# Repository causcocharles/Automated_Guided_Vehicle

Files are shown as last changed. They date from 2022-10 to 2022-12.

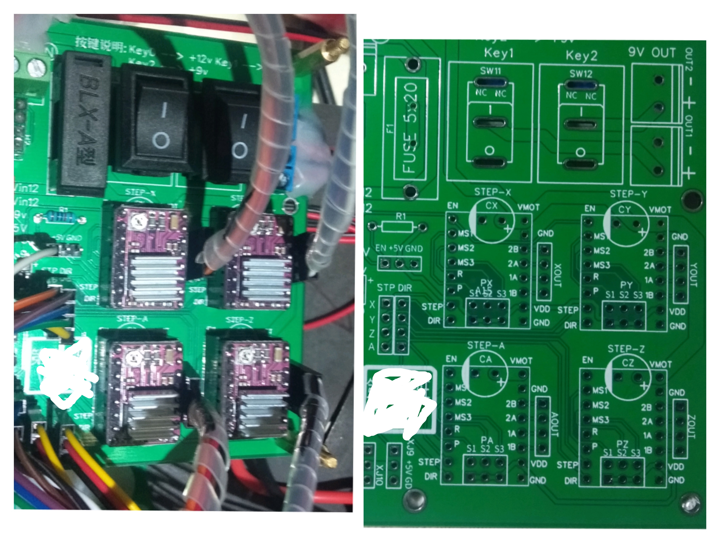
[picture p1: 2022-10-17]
视觉+驱动+机械臂Arduino_21年工训大赛全国季军开源代码/（参考方案）Project_V1.0_四路步进电机驱动板/实物参考图--拓展了其他内容.jpg

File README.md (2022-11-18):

# Automated_Guided_Vehicle
Project codes and reference material of automated guided vehicle for Engineering Innovation Competition. 工程创新大赛智能物流小车项目资料和代码。

目录
- 1. 底盘运动控制文件
- 2. 机械臂控制文件
- 3. 视觉文件
- 4. 机械设计_图纸_建模
  - 底盘
  - 机械臂
  - 载物台
  - 其他 
- 5. 大赛细则及规范
- 6. 其他
- 7. 方案文档
- 8. Sunnybot旧版官方库，内含电机驱动、机械臂控制和OpenMV使用的示例程序
- 9. UTFT库，官方提供的OLED显示转换库
- 10. PS2遥控器官方库
- 11. espbot库——Sunnybot新版库（支持esp32S3）
- 12. Sunnybot-ARM机械臂库（新版）
- 工程实践创新大赛备赛参考资料：https://zhuanlan.zhihu.com/p/365851952
- 视觉相关OpenMV官方指南：https://book.openmv.cc/
- PID算法优化：http://brettbeauregard.com/blog/2011/04/improving-the-beginners-pid-introduction/
- Arduino理论速成指南：https://blog.csdn.net/xq151750111/category_10847153.html
- 配件购买及备赛指南：https://zhuanlan.zhihu.com/p/433498924
- 文本生成二维码网站：https://cli.im/text
- 8/9/10 三个库文件请自行安装，不会的找阿欢

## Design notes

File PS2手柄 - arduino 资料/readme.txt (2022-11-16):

PS手柄 - arduino 通信

1、准备好PS2手柄及arduino UNO R3控制板

2、安装好arduino IDE 后，将PS2X_lib.zip解压到C:\Users\Administrator\Documents\Arduino\libraries文件夹中！

3、按照连接图连接好接收器与控制板（关键一步，基本上都是在这里出错导致无法通信）

4、烧写例程

5、手柄安装上电池后，打开开关 - 电源红灯亮，如果绿灯未亮，点击MODE按钮！打开后，手柄与接收器会自动配对，成功配对后手柄红绿灯常亮，接收器灯常亮。

6、打开串口监视器，点击各个按钮，确定数据通信正常！

如果不正常，检查上面 2、3、4、5步骤！！

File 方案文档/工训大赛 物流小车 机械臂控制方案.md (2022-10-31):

# 工训大赛 | 物流小车 | 机械臂控制方案

## 1. 起点

	机械臂自然折叠状态

## 2. 起点到原料区

	机械臂由折叠到自然展开

	此处自然展开即为环节3的“中立位”

## 3. 原料区

1. 解算位置信息
2. 控制动作
3. **抓取货架上的物料时需遵循任务码顺序，放置到储物槽时需遵循色环的顺序**

### 1. 设计动作组

#### ① 抓取物料

	3

	三个位置抓取动作

#### ② 放置物料

	3

	三个位置放置动作

#### ③ 到中立位

	1

	回位动作

### 2. 动作组顺序

```mermaid
flowchart LR
	A[解算抓取位置] --> B[抓取物料] --> M[回到中立位]
	M --> D[解算放置位置]
	D --> C[放置物料] --> M
	M --> B
	
```

## 4. 原料区到粗加工区

	中立位状态

## 5. 粗加工区

	与环节3动作相反即可

1. 从载物台上放到粗加工区

```mermaid
flowchart LR
	A[解算抓取位置] --> B[抓取物料] --> M[回到中立位]
	M --> D[解算放置位置]
	D --> C[放置物料] --> M
	M --> B
```

2. 从粗加工区抓回到载物台

```mermaid
flowchart LR
	A[解算抓取位置] --> B[抓取物料] --> M[回到中立位]
	M --> D[解算放置位置]
	D --> C[放置物料] --> M
	M --> B
```

## 6. 粗加工区到半成品区

	中立位状态

## 7. 半成品区

无论码垛或是放置不同高度的平台，原来6组与平台互动的动作应略有变化

新增6组动作

### 1. 设计动作组

	6

	6个位置放置动作

```mermaid
flowchart LR
	A[解算抓取位置] --> B[抓取物料] --> M[回到中立位]
	M --> D[解算放置位置]
	D --> C[放置物料] --> M
	M --> B
```

## 8. 循环

## 9. 半成品区到终点

	收缩机械臂

## 函数总结

| 区域 | 函数名 | 作用 |
| --- | --- | --- |
| 基本 | Retract(); | 收缩机械臂 |
| | NeutralPosition(); | 到中立位 |
| | ResolvePlace(); | 解算物料放置顺序 |
| | ResolveGrab(); | 解算物料抓取顺序 |
| 原料区 | ResourceUpperLeftGrab(); | 原料区上层左抓取 |
| | ResourceUpperMiddleGrab(); | 原料区上层中抓取 |
| | ResourceUpperRightGrab();  | 原料区上层右抓取 |
| | ResourceLowerLeftGrab(); | 原料区下层左抓取 |
| | ResourceLowerMiddleGrab(); | 原料区下层中抓取 |
| | ResourceLowerRightGrab();  | 原料区下层右抓取 |
| | StageLeftPlace(); | 载物台左放置 |
| | StageMiddlePlace(); | 载物台中放置 |
| | StageRightPlace(); | 载物台右放置 |
| 粗加工区 | StageLeftGrab(); | 载物台左抓取 |
| | StageMiddleGrab(); | 载物台中抓取 |
| | StageRightGrab(); | 载物台右抓取 |
| | RoughLeftPlace(); | 粗加工区左放置 |
| | RoughMiddlePlace(); | 粗加工区中放置 |
| | RoughRightPlace(); | 粗加工区右放置 |
| 半成品区 | UpperLeftPlace(); | 半成品区上层左放置 |
| | UpperMiddlePlace(); | 半成品区上层中放置 |
| | UpperRightPlace(); | 半成品区上层右放置 |
| | LowerLeftPlace(); | 半成品区下层左放置 |
| | LowerMiddlePlace(); | 半成品区下层中放置 |
| | LowerRightPlace(); | 半成品区下层右放置 |

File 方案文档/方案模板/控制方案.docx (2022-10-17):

第四届浙江省大学生工程训练综合能力竞赛 The 4th ZheJiang Undergraduate Engineering Training Integration Ability Competition | 电路设计方案 Electronic Circuit Design Scheme | | 共 7 页 | 第 1 页
| | | 编 号 | （工作人员填写）

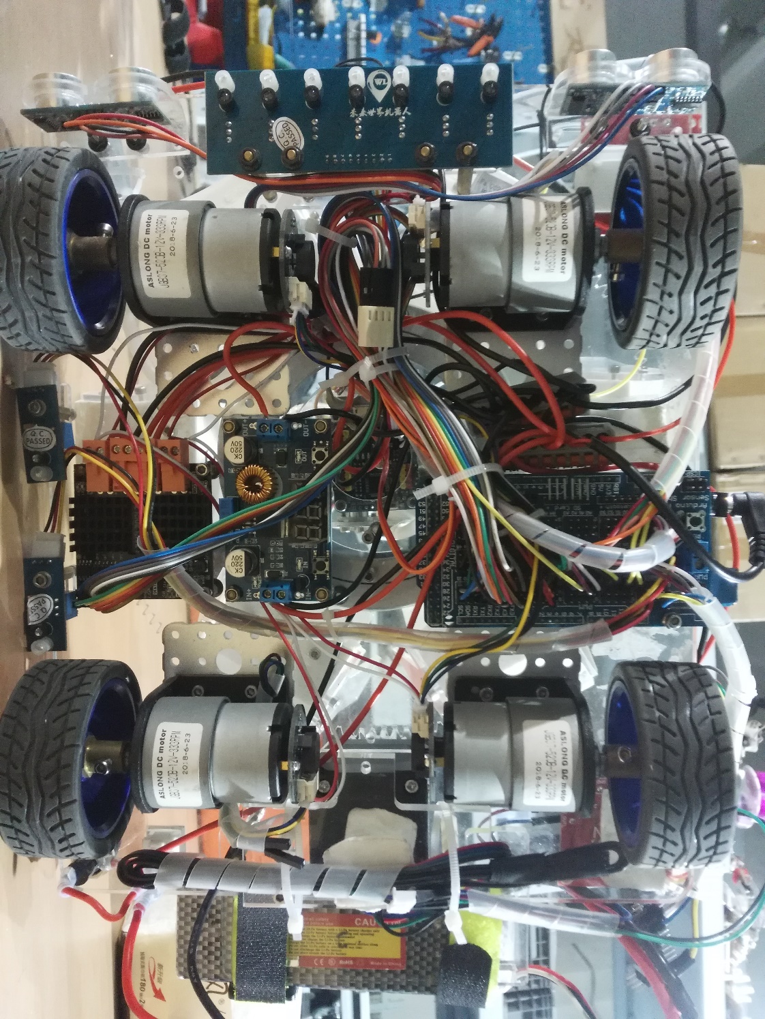
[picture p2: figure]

1、控制系统设计思路

考虑到小车在比赛中需要完成巡线、上坡、扫码、装载物料、避障和放置物料等任务，我们将控制系统分为检测子系统、运算子系统、决策子系统和执行子系统，为了更好地实现功能，在一些环节中我们加入了闭环反馈控制。 我们控制方案的设计如下：

检测子系统负责读取和检测所有传感器的数值。包括读取七路巡线传感器数值、超声波距离传感器数值、扫码信息、轮子（电机）转动圈数等，这些信号是其他各个环节的基础。

运算子系统负责对一些由检测子系统检测到的信号进行处理。将信号转换成具体的数据，并对这些数据通过一定的算法进行处理。例如，对于从七路巡线传感器获得的七个数据（0或1），首先进行加权平均，再对加权平均后的数值进行PID运算，最后得到执行子系统需要的参数。

决策子系统根据检测到的信号作出相应的决策。例如，每检测到一条双侧黑线，相应的计数变量会加一，决策子系统根据这个计数变量的数值让程序进入相应的执行环节（例如，上坡、装载、避障等）。

执行子系统接受决策子系统的命令和运算子系统的数据，来控制具体器件的工作。包括控制舵机、直流电机、步进电机、气泵和电磁阀的工作。舵机由舵机驱动板驱动、直流电机由双路电机驱动板驱动、步进电机由L298N驱动、气泵和电磁阀也由L298N驱动。

整个系统的大部分控制都是开环的，也有一些闭环反馈的控制，比如巡线的PID控制、扫码时小车位置的控制等等。

我们选择 Arduino Mega2560 单片机作为主控板，Arduino Nano单片机作为下位机分担主控板的工作。主控板控制直流电机、舵机、气泵、电磁阀、七路巡线传感器、扫码器、超声波距离传感器等器件的工作以及向下位机发送命令；下位机接受主控板的命令并控制步进电机的工作。

整个系统依靠 7.5V 的锂电池直接供电，由于舵机额定电压低于 7.5V，故另通过一个降压模块实现降压功能间接给舵机供电。另采用三个电机驱动模块分别驱动直流电机、步进电机、电磁阀和气泵。电源正极串联一个 10A 保险丝防止短路。

2、器件选择及实施方案

序号 | 元件 | 数量 | 序号 | 元件 | 数量 | 序号 | 元件 | 数量
1 | 单片机（Mega） | 1 | 7 | 电机驱动 | 3 | 13 | 300度舵机 | 2
2 | 单片机（Nano） | 1 | 8 | 巡线传感器 | 1 | 14 | 180度舵机 | 1
3 | 超声波传感器 | 2 | 9 | 舵机控制板 | 1 | 15 | 气泵 | 1
4 | 直流电机 | 4 | 10 | 稳压模块 | 1 | 16 | 电磁阀 | 3
5 | 扫码模块 | 1 | 11 | 保险丝 | 1 | 17 | 电池 | 1
6 | 步进电机 | 1 | 12 | 轴承 | 1 | 18 | 轮子 | 4

a) 单片机：由于我们对主控板的 IO 口数量要求较高，因此我们选用 ARDUINO 系列的 Mega2560 作为主控板，通过串口实现主控板和舵机控制板、扫码模块之间的通讯，通过三个数字口实现主控板和下位机Nano之间的通讯，以 C 语言作为编程语言。

b) 舵机：舵机采用两个300度大扭力舵机和一个探索者180度大舵机。

c) 步进电机：单步1.8度，精度很高。

d) HC-SR04 超声波模块：该超声波模块使用电压为 5V，静态电流小于 2mA，探测距离范围为 2~450cm，精度可达 0.3cm。

e)电机驱动：两个L298N 用来驱动步进电机和气泵，一个 WSDC2412D用于控制四个直流电机。

f)巡线传感器：七路红外传感器，可调每一路灵敏度。

g)气泵和电磁阀：工作电压都是6V，适当组合后可实现单管路吸气和放气。

h)扫码模块：主控板串口发送指令控制，扫码效率高。

3、总结和体会

控制部分的设计十分重要，需要达到稳、准、快三个要求。在具体实现过程中，出现过许多问题，比如器件之间的相互影响、控制板定时器的冲突等等。这些问题虽然不大，但查找起来却很麻烦，有时一个小小的问题就要花很长时间去发现和解决。不过，只要细心排查、持之以恒，问题总能得到较好的解决。

在我们遇到的问题中，除了程序上的问题，出问题最多的地方是器件间的相互影响，特别是其它器件对主控板的影响。比如，我们之前是用继电器控制电磁阀和气泵的工作，但发现气泵的启动会影响继电器与主控板相连的信号线上的电流突然增大，导致程序重启。这一点是我们在项目开始时没能预料到的。

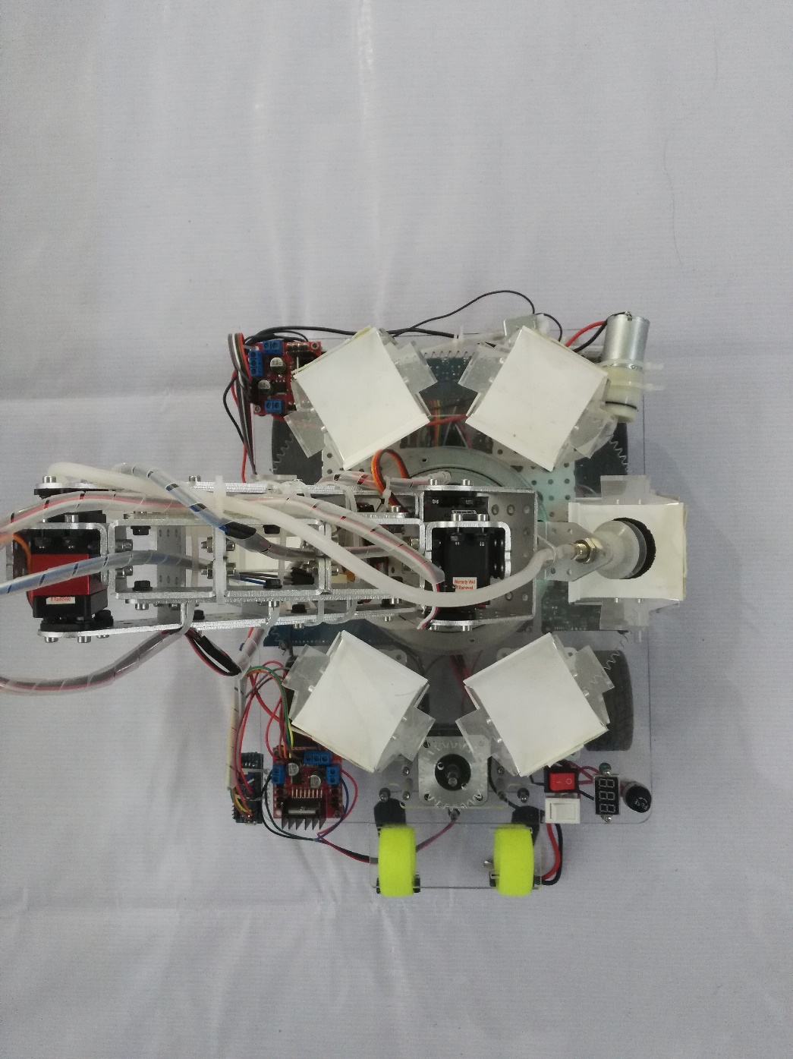
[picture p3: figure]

学校名称：

装

订

线

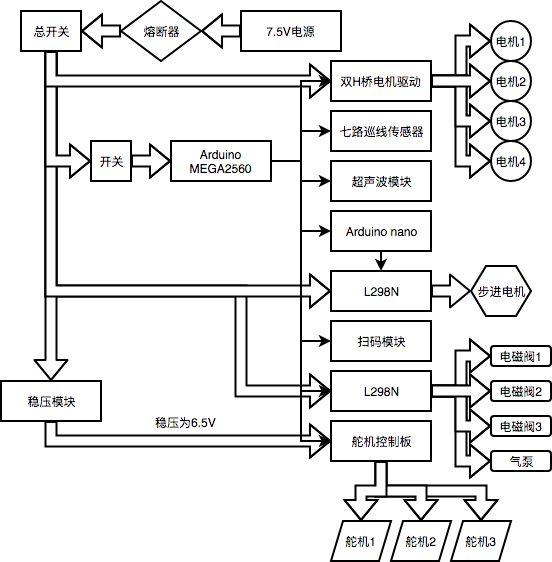
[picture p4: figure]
UZ}E0_H)D)ZBDPM3`ERCNI9

| 说 明 大箭头表示大负载的供电，小箭头表示小负载的供电和信号的传递与控制。以下是具体说明。 1.所有的传感器供电线、地线和信号线通过单片机扩展板连接在主控板 Mega2560 上，即超声波模块、七路巡线传感器、电机编码器和扫码模块。在信号线的连接上，超声波模块和七路巡线传感器的信号口与Mega板的数字口相连，电机编码器的信号口与Mega板的外部中断口相连，扫码模块与Mega板通过串口进行通讯。Nano板的供电线、地线和信号线也与Mega板直接相连，两者之间的通讯通过三个数字口进行。 2.气泵、电磁阀和步进电机需要较高的电压和较大的电流，由电源连接L298N驱动后供电。驱动气泵和电磁阀的L298N由Mega板控制；驱动步进电机的L298N由Nano板控制。 3.所有的舵机由舵机控制板供电和控制，舵机控制板则由电源经稳压模块降压、稳压后供电，并受Mega板串口命令控制。 4.四个直流电机（即电机1、2、3、4）由双H桥电机驱动模块驱动，双H桥电机驱动模块有两路驱动，一路驱动一边的两个轮子。Mega板给双H桥电机驱动提供控制信号，可实现电机的正转、反转和刹车功能。 5.7.5V电源与各器件间通过一个总开关和一个熔断器连接，若电流过大，保险丝烧断，电路断开，可防止器件烧坏。在Mega板供电支路上也串联了一个开关，这个开关的作用是可使舵机控制板单独上电，方便动作组的调节。
| | 电路原理图 | 比 例
| | 第四届浙江省大学生工程训练综合能力竞赛 | 共 页 | 第 3 页

装

订

线

学校名称：

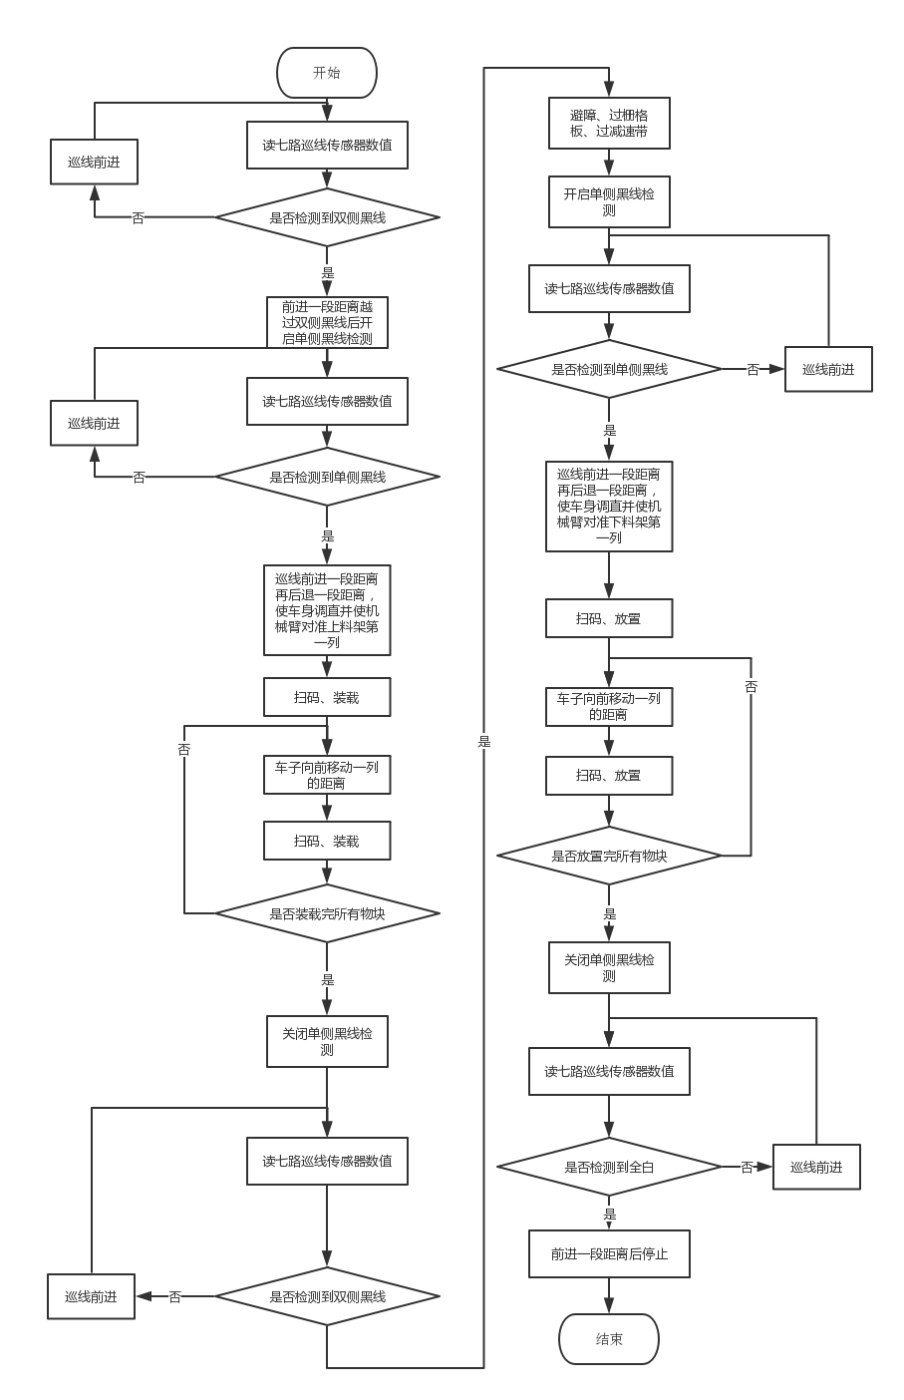
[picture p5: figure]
小车程序流程路

| 说 明 小车的程序运行流程图如左图所示。具体描述如下： 小车以巡线为主体，当检测到第一条双侧黑线后，开始上坡，当检测到第一条单侧黑线后开始物料的装载，当检测到第二条双侧黑线后，开始避障或过栅格板或过减速带，当检测到第二条单侧黑线后，开始下料，当检测到全白后，前进一段距离后停止。上述流程中最主要的三个环节是巡线、定位和避障。 巡线方案：七路灰度传感器接收到灰度信号并返回0或1，通过对返回值的加权平均即可知道小车头部偏离黑线的程度。采用PID算法保证小车能够有效地调整前进方向并实现平滑转弯。 定位方案：为了使小车能够实现非常精确的定位，小车通过采集电机编码器产生的脉冲数进行定位。当小车判断到自己进入到上料区时，先让小车以巡线的方式前进一段距离，然后再退回一定的距离，使小车摆直。接下来小车每次前进一段固定的距离即可定位上料区每一列。在前进一段固定距离的过程中，小车仍保持巡线状态。 避障方案：小车在刚进避障区时会用超声波传感器测量自己与障碍的距离，若距离大于80厘米，则在避障时采用避障路线1，若距离小于80厘米且大于25厘米，则在避障时采用避障路线2，若距离小于25厘米，则在避障时采用避障路线3。小车在避障时的转弯方案是在下达左转命令后，通过采集电机编码器产生的脉冲数使左右两轮转过一定的圈数，调整好适当的圈数差，就能使小车转过固定的角度。
| 程序流程图 | 比 例
| 第四届浙江省大学生工程训练综合能力竞赛 | 共 页 | 第 4 页

装

订

线

学校名称：

/*读取七路灰度传感器数值进行加权计算、计数、设置信号标志变量*/

void readsensor()

{

S1 = digitalRead(sensor1); S2 = digitalRead(sensor2); S3 = digitalRead(sensor3);

S4 = digitalRead(sensor4);S5 = digitalRead(sensor5);S6 = digitalRead(sensor6);

S7 = digitalRead(sensor7);

offest=((-15*4*S1)+(-15*2*S2)+(-15*1*S3)+(15*1*S5)+(15*2*S6)+(15*4*S7))/(S1+S2+S3+S4+S5+S6+S7);

if(S1==HIGH && S2==HIGH && S3==HIGH && S4==HIGH && S5==HIGH && S6==HIGH && S7==HIGH && avoidding==0){

crossroad++;

}

else if(S3==HIGH && S4==HIGH && S5==HIGH && S6==HIGH && S7==HIGH && cansingle==1 && avoidding==0)

{ singleroad++;

offest=((-15*3*S1)+(-15*2*S2)+(-15*1*S3)+(15*1*S5))/(S1+S2+S3+S4+S5);

}

if(crossroad==3 && S1==LOW && S2==LOW && S3==LOW &&S4==LOW &&S5==LOW &&S6==LOW && S7==LOW && avoidding==1) {

jsd=2;

}

if(crossroad==3 && S1==HIGH && S2==HIGH && S3==HIGH &&S4==HIGH &&S5==HIGH &&S6==HIGH && S7==HIGH && avoidding==1) { jsd=1;

}

if(crossroad==-1 && S1==LOW && S2==LOW && S3==LOW &&S4==LOW &&S5==LOW &&S6==LOW && S7==LOW && avoidding==0) {

endding=1;

}

}

/*PID*/

float PID(float e,float kp,float ki,float kd)

{

static float e_s=0,sum=0;//e_s用于保存上一次的误差值，用于计算微分项。Sum用于计算累加和，计算积分项。

float r;

sum+=e;//计算积分累加和

r=kp*e+ki*sum+kd*(e-e_s);//从左至右分别是比例项、积分项、微分项

e_s=e;//保存这一次的误差值用于下一次微分计算

return r;

}

/*巡线*/

void track()

{

value=PID(offest,P,I,D);

speedleft=constrain(prespeed1+value,0,255);

speedright=constrain(prespeed1-value,0,255);

go(speedleft,speedright);

}

关键代码说明

左边是巡线的代码，采用PID算法。

函数readsensor()读取七路灰度传感器数值，加权平均后计算出偏移量offest、 对经过的双侧黑线（crossroad）和单侧黑线（singleroad）进行计数并改变一些信号标志变量的值。

函数 PID(float e,float kp,float ki,float kd)对偏移量e、P参数、I参数和D参数进行 PID运算。

函数track()将函数 PID()运算得到的数值用于左右轮差速的调节。

以下主函数即可实现巡线功能：

void loop()

{

readsensor();

track();

}

采用PID算法可以使车子在转弯过程中行驶得比较平滑。
| | 关键代码说明 | 比 例
| | 第四届浙江省大学生工程训练综合能力竞赛 | 共 页 | 第5 页

装

订

线

学校名称：

/*定位巡线*/ void locatetrack(int defvalA){ attachInterrupt(3, encoder, CHANGE); while(valA!=defvalA){ bmreadsensor(); if(S2==LOW && S3==HIGH ) { foreward(60); }else if(S2==LOW && S3==LOW ) { go(100,20); }else if(S2==HIGH && S3==HIGH ) { go(20,100); } } detachInterrupt(3); valA=0; return; } /*编码器后退*/ void bmback(int defvalA){ attachInterrupt(3, encoder, CHANGE); while(valA!=defvalA){ backward(80,80); } detachInterrupt(3); valA=0; return; } /*中断函数——编码器*/ void encoder(){ valA++; } | 关键代码说明 左边是定位的代码。通过主控板Mega板上的外部中断对电机编码器的脉冲信号进行计数，从而得到车子前进的距离。在这里，因为车子直线行驶，所以只检测一边电机编码器产生的中断信号。 函数 encoder()是中断函数，当编码器产生电平变化的脉冲时，程序进入中断函数， 计数变量valA自增一。 在函数locatetrack(int defvalA)中，while循环内的代码是为了让车子在前进的过程中能够矫正位置，这样保证车身不产生较大的歪斜。当valA增大到 defvalA时，循环结束，这样就能实现车子向前行驶一定的圈数。 函数bmback(int defvalA)实现车子向后退一定的圈数，原理与 locatetrack(int defvalA)相同，但没有车身矫直的功能。
| | 关键代码说明 | 比 例
| | 第四届浙江省大学生工程训练综合能力竞赛 | 共 页 | 第6 页

装

订

线

学校名称：

char outputTable[8] = {0x08, 0x0a, 0x02, 0x06, 0x04, 0x05, 0x01, 0x09};

unsigned int stepTable[4] = {0, 406, 812, 1217};

char table[6] = {0, 1, 2, 3, -2, -1};

unsigned char i = 0;

unsigned int step = 0;

unsigned int targetStep = 0;

char position = 1;

char move = 0;

char dir = 0;

unsigned int speed = 2000; //目标速度900°/s

unsigned int OCR1A_temp;

void setup()

{

pinMode(5, OUTPUT);

pinMode(6, OUTPUT); //5和6用于输出PWM

pinMode(2, INPUT);

pinMode(3, INPUT);

pinMode(4, INPUT); //2、3、4用于通信

DDRB |= 0x0f; //配置9、10、11、12用于输出步进电机信号

TCCR1A = 0x00;

TCCR1B = 0b00001010; //定时器1：8分频，CTC模式

TCCR2A = 0x00;

TCCR2B = 0b00000111; //定时器2：128分频，普通模式

OCR1A = 40000; //初始速度为45°/s

TIMSK2 |= 0b00000001; //启动定时器2溢出中断

TIMSK1 |= 0b00000010; //启动定时器1比较匹配中断

PORTB = outputTable[0];

}

void loop()

{

// put your main code here, to run repeatedly:

char target = 0;

analogWrite(5, 150);

analogWrite(6, 150); //维持转盘上力矩

if (target = GetTarget())

{move = table[(target - position + 6) % 6];

if (move)

dir = move > 0 ? 1 : -1; //判断方向

else

return;

targetStep = stepTable[move > 0 ? move : -move]; //计算步数

analogWrite(5, 255);

analogWrite(6, 255);

OCR1A = 40000; //初始速度为45°/s

OCR1A_temp = 40000;

TIMSK1 |= 0b00000010; //启动中断

TIMSK2 |= 0b00000001;

while (TIMSK1 & 0b00000010) ; //等待此次旋转结束

position = target;

delay(500); //等待转盘停下来

}

}

ISR(TIMER1_COMPA_vect)

{ PORTB = outputTable[(i += dir) % 8];

if (++step >= targetStep) //目标步数达到后

{

step = 0; //步数清零

dir = 0; //方向回正

TIMSK1 &= 0b11111101; //停止中断

}

OCR1A = OCR1A_temp;

}

ISR(TIMER2_OVF_vect)

{ OCR1A_temp -= (OCR1A_temp - speed) >> 3;

if (!((OCR1A_temp - speed) >> 3))

TIMSK2 &= 0b11111110;

}

unsigned char GetTarget()

{int a = digitalRead(2);

int b = digitalRead(3);

int c = digitalRead(4);

int a1 = digitalRead(2);

int b1 = digitalRead(3);

int c1 = digitalRead(4);

if (a == a1 && b == b1 && c == c1)

return a * 1 + b * 2 + c * 4;

else

return 0;}

关键代码说明

该程序使用了单片机Nano中的计时器中断1和2。定时中断2为普通模式，匀速执行，用于计算步进电机的速度，从而实现S型加速以免失步。定时中断1使用CTC模式，通过不断改写OCR1A改变其执行频率。每当定时器1发生中断时向步进电机发送一个脉冲，以此驱动其运行。该程序使用八拍的控制方式驱动步进电机，每个脉冲对应0.9°。经过齿轮减速后精度更高。

Nano板使用3个IO口与上位机进行简单的并行通信以获取需要旋转至的位置。当收到需要旋转至的位置时，Nano板便会计算其相对当前所在位置的距离并算出应该顺时针还是逆时针转动，选择最短的路径驱动步进电机将转盘转至需要的地方。当步进电机未旋转时仍向其通以50%占空比的电流，保持转盘上的扭矩，防止转盘因为外力而转动。

setup()函数用于初始化输入输出引脚和定时器配置。

loop()函数用于循环读取上位机发送的数据。当收到有效数据时便计算出方向和步数，设置好相应变量后启动两个中断，之后便等待中断关闭——步进电机转动完毕——才进行下一次读取。

ISR(TIMER1_COMPA_vect)函数为定时器1比较匹配中断函数，用于向步进电机发送脉冲。每次发送后都会检查步数是否已到达目标值，并且更新OCR1A以调整中断发生频率——即步进电机转速。

ISR(TIMER2_OVF_vect)函数为定时器2溢出中断函数，用于计算步进电机的加速曲线。通过缓冲值temp改变OCR1A的值以改变电机转速。

getTarget()函数用于从上位机读取数据，并设置了一定防抖措施以增加容错度。
| | | 关键代码说明 | 比 例
| | | 第四届浙江省大学生工程训练综合能力竞赛 | 共 页 | 第7 页

装

订

线

学校名称：

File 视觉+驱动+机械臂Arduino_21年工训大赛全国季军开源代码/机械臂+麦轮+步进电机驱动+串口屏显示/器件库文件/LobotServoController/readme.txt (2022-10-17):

本库使用Serial类进行串口通信，占用Arduino的一个硬件串口
接线：舵机控制板的Tx接Arduino的Rx，舵机控制板的Rx接Arduino的Tx，舵机控制板的GND接Arduino的GND

使用库前请初始化串口为波特率9600  不支持其他波特率
实例化LobotServoController类后调用
调用举例：
  LobotServoController Controller(Serial3); //使用Serial3作为与舵机板的通信接口，
                                            //无参数是为Serial
  Controller.moveServo(0,1200,1000)； //0号舵机1000ms移动至1200位置
  
  对于Arduino Leonardo等 atmega32u4的板子默认串口为Serial1，其他均为Serial
  更多函数参看代码，代码有详细注释

发送获取电池电压命令后，需用户自行运行receiveHandle以从串口数据中取出电压信息
获得电池电压后电池电压被保存在类成员batteryVoltage，用户需自行读取该变量，单位为毫伏mv

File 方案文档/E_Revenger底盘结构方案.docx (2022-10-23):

第五届浙江省大学生工程训练综合能力竞赛 The 5th ZheJiang Undergraduate Engineering Training Integration Ability Competition | 作品说明 | 共 1 页 | 第 1 页
| | 编 号 | （工作人员填写）

1、作品名称

E_Revenger

2、小车特点简述
| 作品说明 | 比 例
| 第五届浙江省大学生工程训练综合能力竞赛 | 共 5 页 | 第 1 页

装

订

线

学校名称：

第五届浙江省大学生工程训练综合能力竞赛 The 5th ZheJiang Undergraduate Engineering Training Integration Ability Competition | 结构设计方案 Structure Design Scheme | | 共 2 页 | 第 2 页
| | | 编 号 | （工作人员填写）

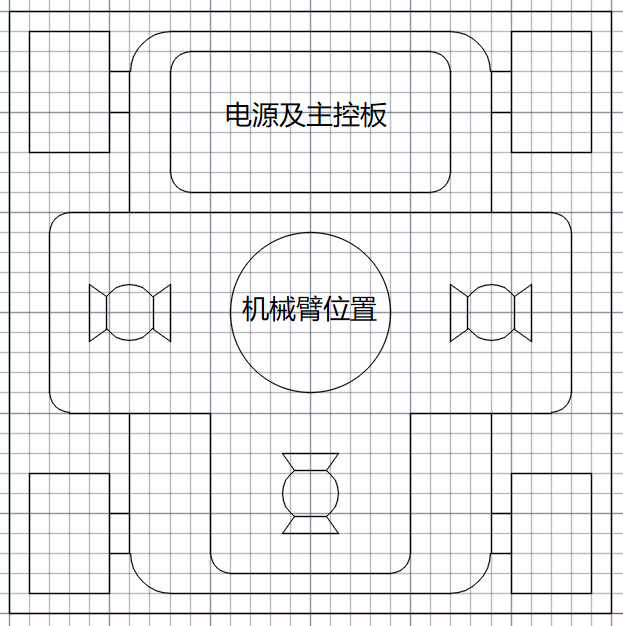
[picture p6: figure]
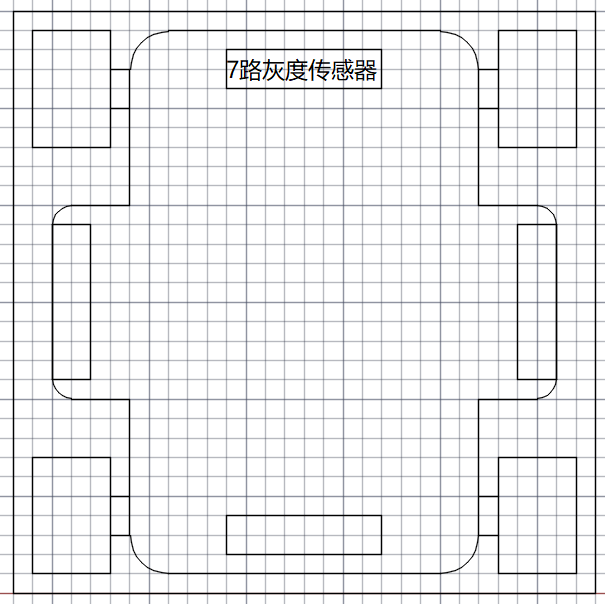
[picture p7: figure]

小车俯视结构示意图 小车仰视结构示意图 | | 1、 底盘机械结构设计思路 根根据比赛要求，小车底盘尺寸不得超过300*300mm，需要有装载码垛的“背包”且一次运载不得超过3个，设计如图所示接结构。 1.1移动部分 移动部分由底板、电机、联轴器和麦克纳姆轮组成，负责小车全部的运动功能。 1）由于麦克纳姆轮结构的特殊性，控制平动和转动方向要求4个轮子同时驱动，因此装配了4个电机。 2)小车主要通过降低小车重心的办法来提高整车稳定性，底板高度低。 3)为维持小车运动过程中的平衡，将机械臂设在底盘正中心，并合理布局电源及控制元件。 4)底盘长280mm，宽180mm。 1.2寻迹部分 底盘四边各设置一排7路灰度传感器。 1）为了便于计算，灰度传感器的布局采用高度对称的布局，四边的灰度传感器距离底盘中心相等。 2）若环境光对灰度传感器干扰较大，可考虑在周围加一层挡板。 1.3装载部分 装载部分是一个3D打印的固定件，水平，为“T”字形。 1)为使物块不翻倒，将载物台固定，调整机械臂位姿去抓。 2)为提高物块放置时和抓取时的准确性，将物块横置

学校名称：

装

订

线

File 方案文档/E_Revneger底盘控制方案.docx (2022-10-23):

第四届浙江省大学生工程训练综合能力竞赛 The 4th ZheJiang Undergraduate Engineering Training Integration Ability Competition | 电路设计方案 Electronic Circuit Design Scheme | | 共 4 页 | 第 1 页
| | | 编 号 | （工作人员填写）

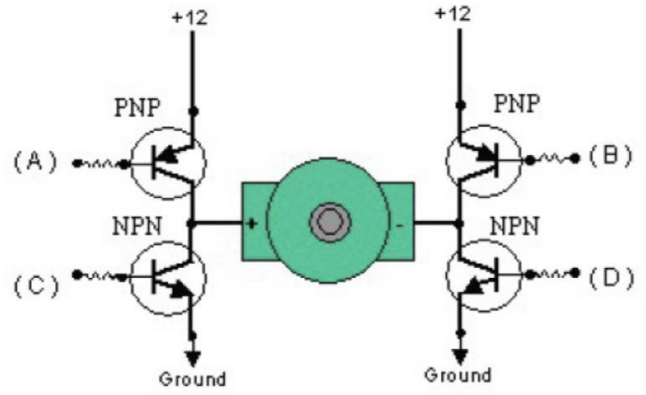
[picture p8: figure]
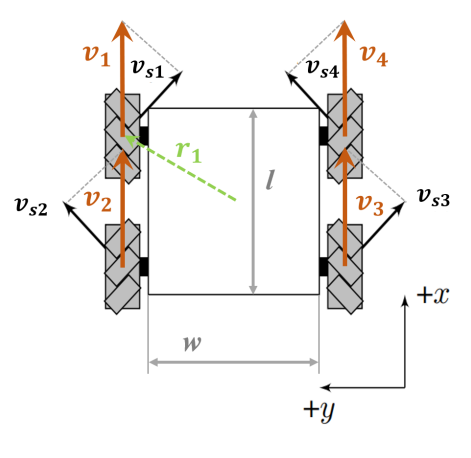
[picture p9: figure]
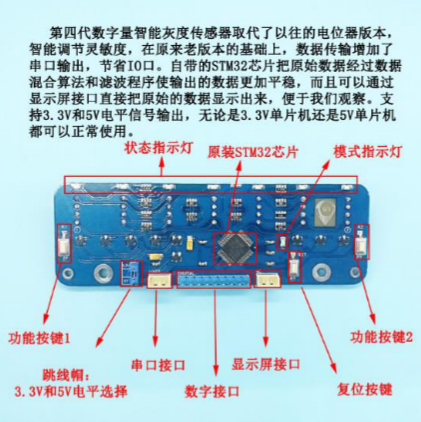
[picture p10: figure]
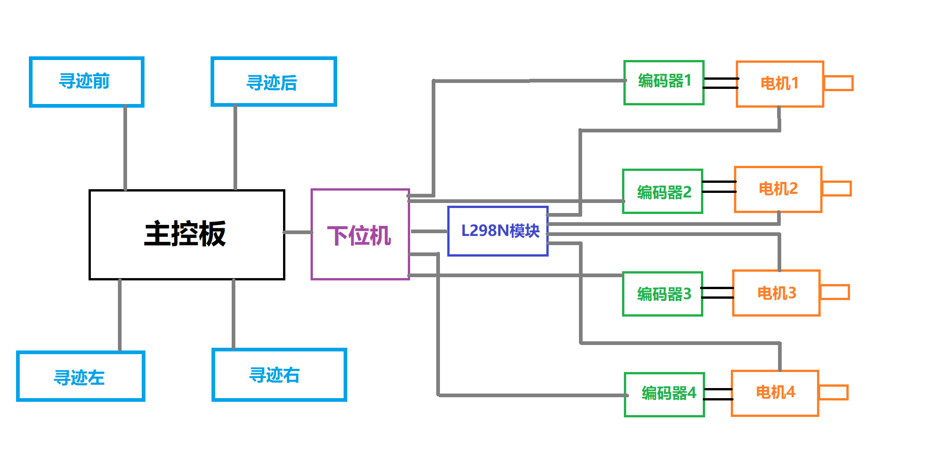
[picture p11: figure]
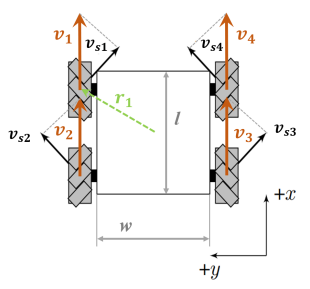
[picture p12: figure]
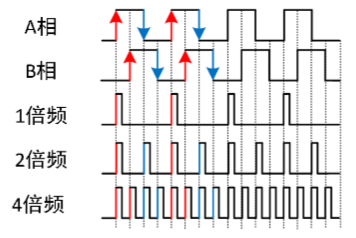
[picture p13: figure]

底盘运动模块设计方案

1.电路层面

电路层面底盘主要分为驱动和寻迹两个模块。

驱动模块方面，由于工程实践与创新大赛的比赛场地是很规则的方形，且循迹的黑色轨迹为正交的直线，我们选择采用麦克纳姆四轮驱动进行跑图。使用麦轮运动的优点是它不需要任何旋转，只需平移即可到达任何目标地点，而从左侧示意图上看，平移则图上对角麦轮的有效速度是平行同向的，这就使本来四路使能端分别驱动四轮的电路可以简化为对角的电机共用一个使能端口，但是由于实际运动过程中存在误差，小车的实际转速差或打滑会导致小车旋转，因此需要将角速度分量叠加到小车上，因此仍然使用4个使能端口输出PWM波控制，每个接口另外两个数字信号引脚控制小车前进后退和停止。所以麦轮小车共占用8个数字输出端口和4个模拟输出端口。由于控制板不能直接提供驱动电机的电流，使用L298N芯片进行转接驱动，芯片最主要的是一个H桥电路结构如图所示，我们将使用将2个L298N芯片集成在一个主板上的模块。

底盘除了4个电机还有一个循迹传感器模块。我们使用四边分别7路灰度传感器的检测装置识别轨迹（没有找到其他适合尺寸的传感器）。在4边分别装配是为了减少车轮打滑或转速差造成的角度偏差。灰度传感器原理在这里不加赘述，实际使用只要知道它会返回给控制板一个范围内的值，表征反射光强度，我们可以根据实际情况调节各灰度的阈值使黑色返回1，其他颜色返回0（如果是数字传感器不需要人为设定阈值，直接返回0和1）。 为了节省I-O口，尽量使用串口与主板通信。

虽然用寻迹模块做闭环控制可以使小车在轨迹上运行，但为了保证稳定性，我们不能只依赖寻迹模块去调控小车的电机转速，由于4个电机参数有细微的差异，输入相同的电压时转速可能不同，何况输入电压值也难以保证相同，因此需要利用电机自带的编码器反馈一个实际转速的值，根据这个值用PID方式调节转速至目标转速，保证小车沿直线行进。

由于主控板可能引脚数不足，底盘的电机驱动模块暂定使用下位机，同上位机利用串口通信交互参数。

综上，底盘电路结构的框架如左图所示。

底盘各类输入输出端口占用数量统计：

模块 | 占用数字I-O口 | 占用模拟输入口 | 占用PWM输出口 | 占用串口
电机驱动 | 2*4 | 0/4 | 1*4 | 0
电机编码器 | 2*4 | 0 | 0 | 0
寻迹模块 | 0 | 0 | 0 | 4
总计 | 16 | 0/4 | 4 | 4

2.控制算法层面

首先是麦克纳姆轮的方向控制。基础功能是实现底盘在X-Y两个方向的平动，进阶功能是底盘绕中心旋转来调整方向，均涉及简单的逆运动学解算知识。如左图所示，我们暂且将前进方向作为X轴正方向，左侧作为Y轴正方向，我们所希望达到的目的是给定X-Y轴向速度分量，程序将其分解到各个电机的转速上去。麦克纳姆轮的特点是电机的角速度沿Y轴方向，但提供的线速度是沿与地面接触辊子的轴向方向，因此有效速度分量为与X-Y轴分别夹45°的方向。不妨如图所示设置有效速度的正方向。线速度大小要根据小车的实际尺寸和轮径算出，此处从略。要保证小车平移而不旋转，若相对于世界坐标系对角电机转动方向相反，则另外两个电机转向也只能相反，最后只会一动不动。因此对角轮一定是同时向前或者向后旋转，左上和右下轮提供y = -x直线方向的速度，同理右上和坐下轮提供y = x方向分量，则左上轮转速w = k(vx-vy)，同理可求得其他轮的转速。而要实现旋转只需要将角速度分解得到的转速分量和线速度的转速分量做线性叠加即可，注意顺时针和逆时针的正负号问题。

编码器读取电机转速只要在一定时间内读取脉冲数量乘一个比例系数即可，根据从A端口和B端口读到的脉冲相位差可以看出电机是顺时针还是逆时针旋转。

寻迹模块采用寻迹的PID算法，为每个传感器加上适当的速度权重，根据实际读到的值线性叠加实现变速回调。

为了使系统更快速而稳定地达到目标状态（角度和速度），电机调速采用PID算法，输入量为目标速度和电机编码器返回速度，输出PWM参数，利用J-Scope PID调试工具调整PID系数至最适。

以上均为机器人本身的微观控制层面的算法分析，为了实现跑图，下述宏观调整策略：

全局控制策略是分阶段实现控制，设置控制变量来判断此时应处于任务的哪个阶段。当小车出发时先循迹，读到目标个数的黑色横轨道(7个传感器全返回黑色对应数值)，停止进入下一个阶段。进行特定任务时配合视觉系统给出的参数调整小车的位姿。整个控制方式以闭环控制为主，在局部使用开环控制，如为了防止计数器重复技术，在读到横条给计数器计数+1的同时关闭计数器一段很小的时间段，保证小车越过横条再重新打开。为了防止每个阶段误差的累计，每个阶段任务完成后需要原地调整姿态。

学校名称：

装

订

线

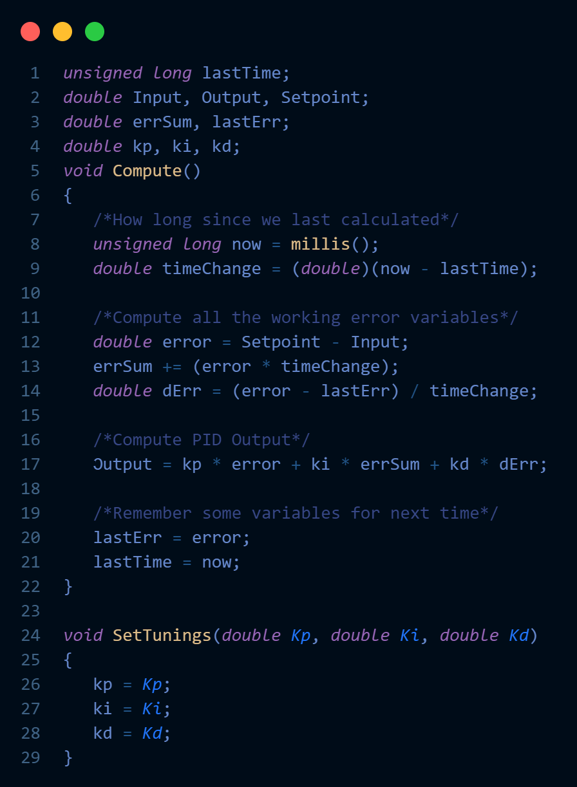
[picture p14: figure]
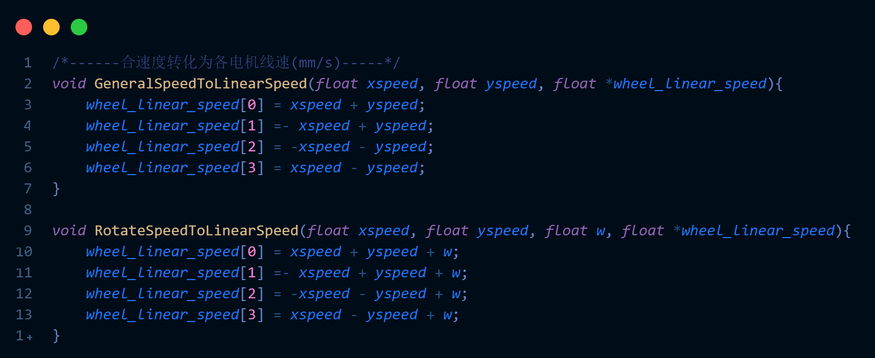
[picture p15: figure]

| 关键代码说明 PID算法基本代码实现（图1）： 用SetTunings()函数为kp,ki,kd赋值，在中断服务函数或其回调函数里调用Compute()函数实现PID控速。 麦克纳姆轮速度解算（图2）： GeneralSpeedToLinearSpeed()函数仅控制平动转速，RotateSpeedToLinearSpeed()函数叠加旋转速度分量。
| | 关键代码说明 | 比 例
| | 第四届浙江省大学生工程训练综合能力竞赛 | 共 页 | 第5 页

装

订

线

学校名称：

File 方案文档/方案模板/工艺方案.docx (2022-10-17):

第五届浙江省大学生工程训练综合能力竞赛 The 5th ZheJiang Undergraduate Engineering Training Integration Ability Competition | | | | | 自制件1机械加工工艺过程卡片 Machining Process Card | | | | | 产品名称 | 小车 | 生产纲领 | 5000件/年 | 共 10页 | | 第 1 页
| | | | | | | | | | 零件名称 | 底板 | 生产批量 | 420件/月
材料 | 5mm有机玻璃 | 毛坯种类 | 板材 | 毛坯外形尺寸 | 不定 | 每毛坯可制作件数 | | | 1 | 每台件数 | | 1 | | 备注
序 号 | 工序 名称 | 工序内容 | | | 工 序 简 图 | | | | 机床 | 夹具 | | 刀具 | | 量具 辅具 | 工时 （min）

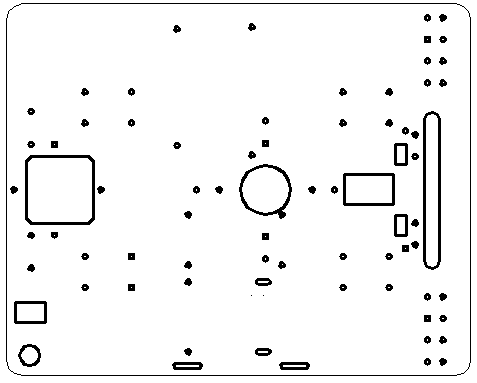
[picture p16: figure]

1 | 切割内孔 | 1)将待割板材放入切割机内，进行定位走边框。 2)按顺序切割 4*4 个电机固定孔、1个步进电机方孔、1个中间圆孔、1个熔断器孔、46个3.2mm直径螺母孔及其他相关孔位。 | | | | | | | CO2激光切割机 | 无 | | CO2激光器 | | 游标卡尺 | 5

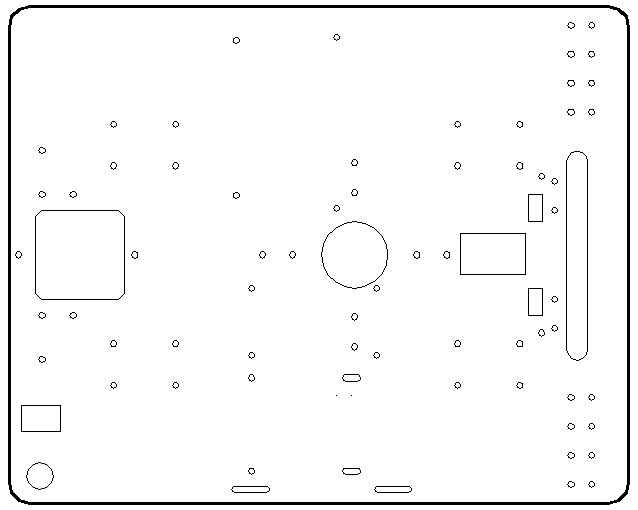
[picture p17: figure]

2 | 切割外轮廓 | 1) 切割底板的外轮廓。 2) 将底板与5mm有机玻璃板分离。 | | | | | | | CO2激光切割机 | 无 | | CO2激光器 | | 游标卡尺 | 5
| | | | | 编制 | | 审核 | | 标准化 | | | 会签
标记 | 处数 | 更改文件号 | 签字 | 日期 | 日期 | | 日期 | | 日期 | | | 日期

装

订

线

学校名称：

第五届浙江省大学生工程训练综合能力竞赛 The 5th ZheJiang Undergraduate Engineering Training Integration Ability Competition | 自制件1加工工艺分析 Processing Technology Analysis | 产品名称 | 小车 | 生产纲领 | 5000件/年 | 共 10页 | 第 2 页
| | 零件名称 | 底板 | 生产批量 | 420件/月

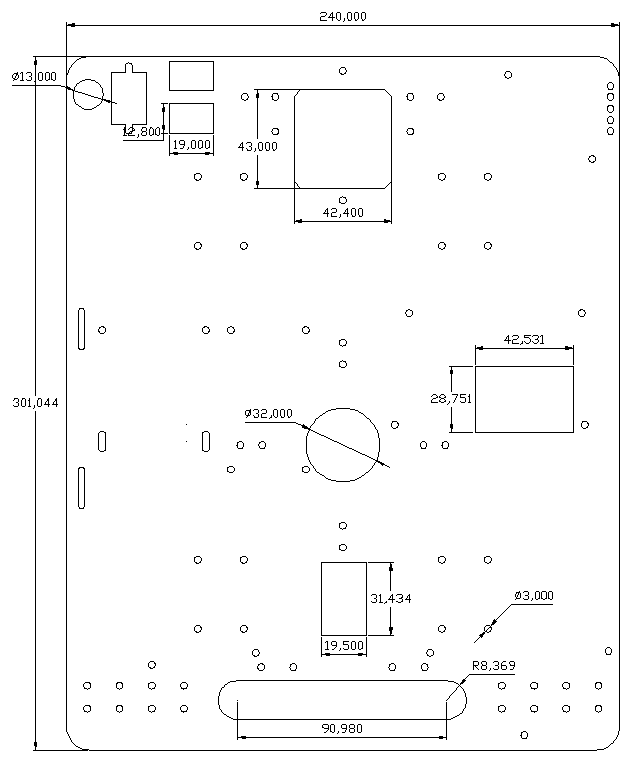
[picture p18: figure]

1、 零件的选材和加工工艺：

a) 底板需满足以下功能：

支撑功能：小车上部要支撑机械臂和载物台，两者质量约占到小车的一半，小车下部安装轮胎和各种电子器件，受到来自地面的支持力，整个小车底板需要承受较大弯矩，因此它需要较强的抗弯能力；

安装功能：为了给小车的储物部分留有足够的空间，保证小车上方的整洁，我们决定将电路部分的大多数都放在底板下方，同时下方还要安装电机以及各种相关元器件，因此需要合理安排各种零部件的布局和安装孔位的分布。

b) 材料分析：

有机玻璃学名为聚甲基丙烯酸甲酯，具有较好的透明性、稳定性、力学性能和耐候性，具备易加工、外观优美等特点。对于底板这种承受较大弯矩且需要多次修改的部件，有机玻璃再合适不过。

c) 工艺选择：

加工亚克力板可供选择的工艺有雕铣和激光切割。亚克力本身具有良好的热塑性，且加热冷却后尺寸稳定，易于成型。加工小零件时两者效率相差无几，但加工类似底板的大零件时，雕铣将面临难以装夹、

切屑过多难以处理、加工步骤繁琐，需要换刀等问题。

而激光切割只需要调整激光功率即可轻松实现轮廓切割，图案扫描雕刻，选择激光切割加工亚克力底板是一种我们能做的最优选择。

2、 零件精度分析：

激光切割会造成轮廓线约 0.2mm 的误差，但底板上的孔主要用于定位，孔径精度影响不大，设计时孔径一般设置为3.2mm即可。

装

订

线

学校名称：

第五届浙江省大学生工程训练综合能力竞赛 The 5th ZheJiang Undergraduate Engineering Training Integration Ability Competition | | | | | 自制件2机械加工工艺过程卡片 Machining Process Card | | | | | | 产品名称 | 小车 | 生产纲领 | 5000件/年 | 共 10页 | 第 3 页
| | | | | | | | | | | 零件名称 | 支架 | 生产批量 | 420件/月
材料 | 5mm有机玻璃 | 毛坯种类 | 板型 | 毛坯外形尺寸 | 不定 | | 每毛坯可制作件数 | | | 1 | 每台件数 | | 1 | | 备注
序 号 | 工序 名称 | 工序内容 | | | 工 序 简 图 | | | | | 机床 | 夹具 | | 刀具 | | 量具 辅具 | 工时 （min）

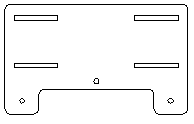
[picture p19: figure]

1 | 电池支架 | 1）将待割板材放入切割机内，进行定位，走边框。2）按顺序切割3个定位螺丝孔和4个长方形孔位。3）切割外轮廓，并将底板与5mm有机玻璃板分离。 | | | | | | | | CO2激光切割机 | 无 | | CO2激光器 | | 游标卡尺 | 2
2 | 步进电机支架 | 1）将待割板材放入切割机内，进行定位，走边框。2）切割4个m3的螺丝孔。 3）切割外轮廓，并将底板与5mm有机玻璃板分离。 | | | | | | | | CO2激光切割机 | 无 | | CO2激光器 | | 游标卡尺 | 2

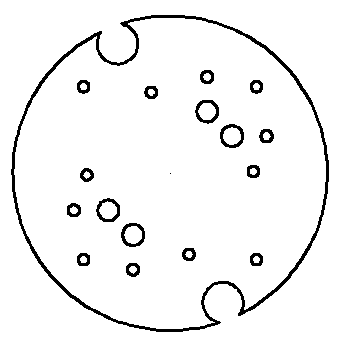
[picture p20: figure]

3 | 机械臂支架 | 1）将待割板材放入切割机内，进行定位，走边框。2）按顺序切割12个定位螺丝孔和直径6mm的圆 孔。 3）切割外轮廓，并将底板与5mm有机玻璃板分离。 | | | | | | | | CO2激光切割机 | 无 | | CO2激光器 | | 游标卡尺 | 2
| | | | | 编制 | | | 审核 | | 标准化 | | | 会签
标记 | 处数 | 更改文件号 | 签字 | 日期 | 日期 | | | 日期 | | 日期 | | | 日期

装

订

线

学校名称：

第五届浙江省大学生工程训练综合能力竞赛 The 5th ZheJiang Undergraduate Engineering Training Integration Ability Competition | 自制件2加工工艺分析 Processing Technology Analysis | 产品名称 | 小车 | 生产纲领 | 5000件/年 | 共 10页 | 第 4 页
| | 零件名称 | 支架 | 生产批量 | 420件/月

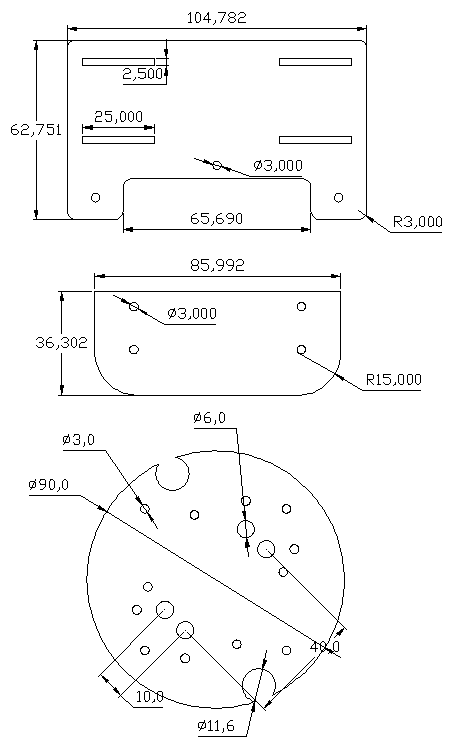
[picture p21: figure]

1、 零件的选材和加工工艺：

a) 支架需满足以下功能：

支撑功能：各支架分别需要支撑电池、步进电机和机械臂，会承受较大的弯矩。

安装功能：机械臂支架的下方还需要安装舵机控制板，需要合理设置孔位以方便我们用数据线连接舵机控制板和电脑。

b) 材料分析：

有机玻璃学名为聚甲基丙烯酸甲酯，具有较好的透明性、稳定性、力学性能和耐候性，具备易加工、外观优美等特点。对于支架这种需要承受弯矩且对定位要求比较高的零件，选择使用有机玻璃比较合适。

c) 工艺选择：

加工亚克力板可供选择的工艺有雕铣和激光切割。亚克力本身具有良好的热塑性，且加热冷却后尺寸稳定，易于成型。雕铣加工操作复杂、加工步骤繁琐，且会产生较多切屑。

而激光切割只需要调整激光功率即可轻松实现轮廓切割，图案扫描雕刻，选择激光切割加工亚克力底板是一种我们能做的最优选择。

2、 零件精度分析：

激光切割会造成轮廓线约 0.2mm 的误差，由于这几个支架主要起支撑作用，对轮廓的精度要求不高。而支架内部的孔主要由定位，孔径对它的影响不大，孔径一般设置为3.2mm即可。

装

订

线

学校名称：

第五届浙江省大学生工程训练综合能力竞赛 The 5th ZheJiang Undergraduate Engineering Training Integration Ability Competition | | | | | 自制件3机械加工工艺过程卡片 Machining Process Card | | | | | | 产品名称 | 小车 | 生产纲领 | 5000件/年 | 共 10页 | 第 5 页
| | | | | | | | | | | 零件名称 | 齿轮组 | 生产批量 | 420件/月
材料 | 5mm有机玻璃 | 毛坯种类 | 板型 | 毛坯外形尺寸 | 不定 | | 每毛坯可制作件数 | | | 1 | 每台件数 | | 1 | | 备注
序 号 | 工序 名称 | 工序内容 | | | 工 序 简 图 | | | | | 机床 | 夹具 | | 刀具 | | 量具 辅具 | 工时 （min）

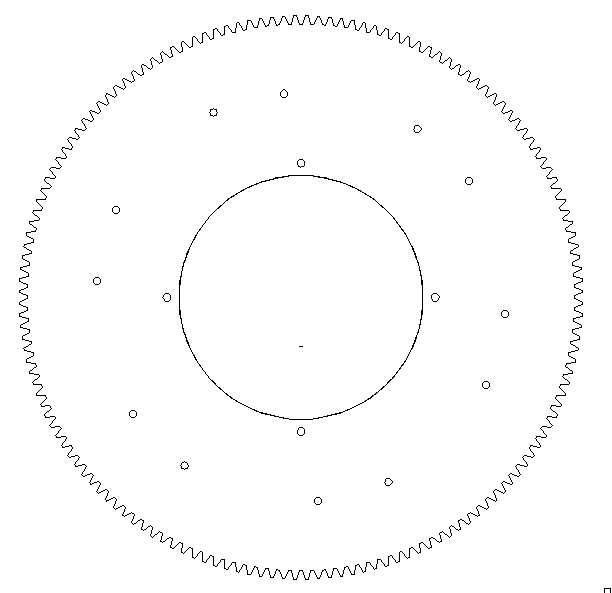
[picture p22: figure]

1 | 大齿轮切割 | 1)将待割板材放入切割机内，进行定位，走边框。2)按顺序切割内孔和外轮廓将底板与5mm有机玻璃板分离。 | | | | | | | | CO2激光切割机 | 无 | | CO2激光器 | | 游标卡尺 | 3
2 | 小齿轮切割 | 1)将待割板放入切割机内，进行定位，走边框。2)切割1个步进电机轴孔和2个螺丝孔孔 3)切割小齿轮外轮廓，将小齿轮齿轮与5mm有机玻璃板分离。 | | | | | | | | CO2激光切割机 | 无 | | CO2激光器 | | 游标卡尺 | 1

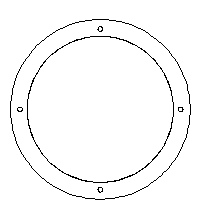
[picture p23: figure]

3 | 齿轮垫片切割 | 1)将待割板放入切割机内，进行定位，走边框。2)切割4个螺丝孔和1个直径100mm的内孔。 3)切割外轮廓，将齿轮垫片与5mm有机玻璃板分离。 | | | | | | | | CO2激光切割机 | 无 | | CO2激光器 | | 游标卡尺 | 2
| | | | | 编制 | | | 审核 | | 标准化 | | | 会签
标记 | 处数 | 更改文件号 | 签字 | 日期 | 日期 | | | 日期 | | 日期 | | | 日期

装

订

线

学校名称：

第五届浙江省大学生工程训练综合能力竞赛 The 5th ZheJiang Undergraduate Engineering Training Integration Ability Competition | 自制件3加工工艺分析 Processing Technology Analysis | 产品名称 | 小车 | 生产纲领 | 5000件/年 | 共 10页 | 第 6 页
| | 零件名称 | | 生产批量 | 420件/月

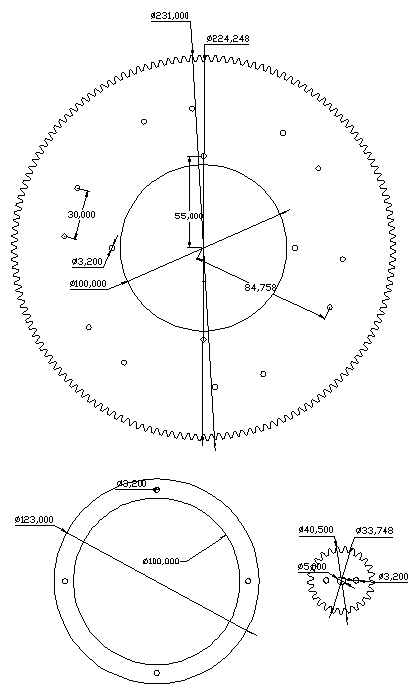
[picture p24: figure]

1、 零件的选材和加工工艺：

a) 齿轮组需满足以下功能：

支撑功能：齿轮上方需要安装物块座，会给予齿轮一定压力和弯矩。

传动功能：步进电机通过大小齿轮的啮合来传动扭矩，两个齿轮均会受到较强的扭矩，同时为了保证两个齿轮间能够顺利啮合，所以必须保证齿轮有很高的强度和精度。

b) 材料分析：

有机玻璃学名为聚甲基丙烯酸甲酯，具有较好的透明性、稳定性、力学性能和耐候性，具备易加工、外观优美等特点。对于齿轮这种精度和强度要求都比较高的零件，选择有机玻璃再合适不过。

c) 工艺选择：

加工亚克力板可供选择的工艺有雕铣和激光切割。亚克力本身具有良好的热塑性，且加热冷却后尺寸稳定，易于成型。加工小零件时两者效率相差无几，但加工类似底板的大零件时，雕铣将面临难以装夹、切屑过多难以处理、加工步骤繁琐，需要换刀等问题。

而激光切割只需要调整激光功率即可轻松实现轮廓切割，图案扫描雕刻，选择激光切割加工亚克力底板是一种我们能做的最优选择。

2、 零件精度分析：

激光切割会造成轮廓线约 0.2mm 的误差，但由于两个齿轮的直径相对于0.2mm都比较大，加上齿轮间的补偿作用，因此这点误差可以忽略。

装

订

线

学校名称：

第五届浙江省大学生工程训练综合能力竞赛 The 5th ZheJiang Undergraduate Engineering Training Integration Ability Competition | | | | | 自制件4机械加工工艺过程卡片 Machining Process Card | | | | | | 产品名称 | 小车 | 生产纲领 | 5000件/年 | 共 10页 | 第7 页
| | | | | | | | | | | 零件名称 | 物块座 | 生产批量 | 420件/月
材料 | PLA | 毛坯种类 | | 毛坯外形尺寸 | | | 每毛坯可制作件数 | | | | 每台件数 | | | | 备注
序 号 | 工序 名称 | 工序内容 | | | 工 序 简 图 | | | | | 机床 | 夹具 | | 刀具 | | 量具 辅具 | 工时 （min）

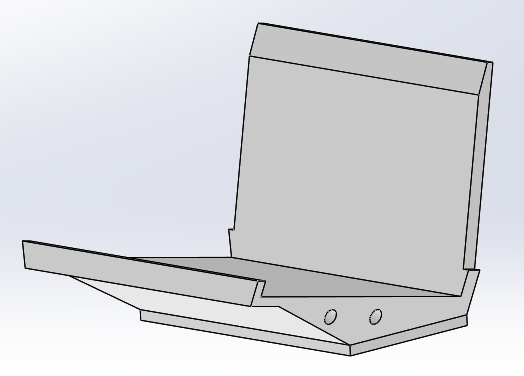
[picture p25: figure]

1 | 3D建模 | 1)测量所需放置物块的外形尺寸和位置尺寸。 2)用 SolidWorks三维建模软件画出横截面的草图，拉伸形成三维模型。 3)使用拉伸切除的命令在模型两侧切出15度的倾角。 4)在模型底面及两侧共打6个2.9mm的螺丝孔。 5)将模型导入到3D 打印机处理软件中进行处理。 | | | | | | | | 电脑 | 无 | | 无 | | 游标卡尺 | 120


2 | 3D打印 | 1)使用旋转命令使模型底面与水平面平齐。 2)将模型等比例复制6个。 3)选择打印层高为0.1mm，填充密度40%。 4)选择打印机热床温度50度，挤出头温度205度。5)连接3D打印机，开始打印。 | | | | | | | | 3D打印机 | 热床 | | 挤出头 | | 游标卡尺 | 600
| | | | | 编制 | | | 审核 | | 标准化 | | | 会签
标记 | 处数 | 更改文件号 | 签字 | 日期 | 日期 | | | 日期 | | 日期 | | | 日期

装

订

线

学校名称：

第五届浙江省大学生工程训练综合能力竞赛 The 5th ZheJiang Undergraduate Engineering Training Integration Ability Competition | 自制件4加工工艺分析 Processing Technology Analysis | 产品名称 | 小车 | 生产纲领 | 5000件/年 | 共 10页 | 第 8 页
| | 零件名称 | 物块座 | 生产批量 | 420件/月


1、 零件的选材和加工工艺：

a) 物块座需满足以下功能：

储物功能：物块座内需要能储存物块，而且要使得物块在物块座内不能随意移动。

拿放功能：物块座的形状要设计成开式，便于机械臂对物块的拿取和放置。

b) 材料分析：

聚乳酸（PLA）是一种对环境影响较低的热敏性硬塑料。它不是石化产品，而是一种可再生资源（淀粉类）的衍生物，是一种较为新型环保的塑料，有非常好的打印特质：打印熔融时没有 ABS那样刺鼻的气味，打印出来的模型硬度和机械强度都不错，能够胜任该物块座的工作。

c) 工艺选择：

加工PLA可选择的工艺有热塑和3D打印。热塑的加工成本高，加工流程复杂繁琐，适合大批量生产。而3D打印属于快速成型的一种通过加热挤压热塑性原材料，逐层熔融沉积，最后形成三维实体，加工速度快，成本低，而且可以加工几何形状复杂的零件。因此我们选择使用3D打印来制作这造这个零件。

2、 零件精度分析：

我们采用的3D 打印工艺外边框存在 0.1mm 的误差，孔径误差根据材料的熔融温度和冷却速度不同精度差距较大且无法提前预测，需要依靠锉刀和美工刀进行修整。

装

订

线

学校名称：

第五届浙江省大学生工程训练综合能力竞赛 The 5th ZheJiang Undergraduate Engineering Training Integration Ability Competition | | | | | 自制件5机械加工工艺过程卡片 Machining Process Card | | | | | | 产品名称 | 小车 | 生产纲领 | 5000件/年 | 共 10页 | 第9 页
| | | | | | | | | | | 零件名称 | 物块座挡板 | 生产批量 | 420件/月
材料 | PLA | 毛坯种类 | | 毛坯外形尺寸 | | | 每毛坯可制作件数 | | | 12 | 每台件数 | | 12 | | 备注
序 号 | 工序 名称 | 工序内容 | | | 工 序 简 图 | | | | | 机床 | 夹具 | | 刀具 | | 量具 辅具 | 工时 （min）


1 | 切割内孔 | 1)将待割板材放入切割机内，进行定位，走边框。 2)切割12个挡板的螺丝孔，每个挡板有2个螺丝孔。 | | | | | | | | CO2激光切割机 | 无 | | CO2激光器 | | 游标卡尺 | 4


2 | 切割轮廓 | 1)切割外轮廓，并将12个挡板都从亚克力板上分离下来。 | | | | | | | | CO2激光切割机 | 无 | | CO2激光器 | | 游标卡尺 | 4
| | | | | 编制 | | | 审核 | | 标准化 | | | 会签
标记 | 处数 | 更改文件号 | 签字 | 日期 | 日期 | | | 日期 | | 日期 | | | 日期

装

订

线

学校名称：

第五届浙江省大学生工程训练综合能力竞赛 The 5th ZheJiang Undergraduate Engineering Training Integration Ability Competition | 自制件5加工工艺分析 Processing Technology Analysis | 产品名称 | 小车 | 生产纲领 | 5000件/年 | 共 10页 | 第 10 页
| | 零件名称 | 物块座挡板 | 生产批量 | 420件/月


1、 零件的选材和加工工艺：

a) 挡板需满足以下功能：

限位功能：物块需要通过挡板来进行横向的限位，因此需要设计好挡板的形状。

滑道功能：通常物块并不是正好直接落在物块座上，而是通过挡板滑到物块座内，因此挡板的表面必须光滑。

b) 材料分析：

有机玻璃学名为聚甲基丙烯酸甲酯，具有较好的透明性、稳定性、力学性能和耐候性，具备易加工、表面光滑等特点。

c) 工艺选择：

加工亚克力板可供选择的工艺有雕铣和激光切割。亚克力本身具有良好的热塑性，且加热冷却后尺寸稳定，易于成型。加工单个小零件时两者效率相差无几，但加工数量有12个的物块座挡板时，雕铣将面临难以装夹、切屑过多难以处理、加工步骤繁琐，需要换刀等问题。

而激光切割只需要调整激光功率即可轻松实现轮廓切割，图案扫描雕刻，选择激光切割加工亚克力底板是一种我们能做的最优选择。

2、 零件精度分析：

激光切割会造成轮廓线约 0.2mm 的误差，但挡板上的孔主要用于定位，孔径精度影响不大，设计时孔径一般设置为3.2mm即可。

装

订

线

学校名称：

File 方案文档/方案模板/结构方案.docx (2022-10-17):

第五届浙江省大学生工程训练综合能力竞赛 The 5th ZheJiang Undergraduate Engineering Training Integration Ability Competition | 作品说明 | 共 5 页 | 第 1 页
| | 编 号 | （工作人员填写）

1、作品名称

泰迪

2、小车特点简述

在制造业向工业 4.0、中国制造 2025 和智能制造方向发展的背景下，围绕“智能物流+创客”的主题，模拟离散制造业的智能物流小车——“泰迪”应运而生。它是一种直排四轮驱动式的智能机器人，拥有三种避障路线、三自由度机械臂、气动吸盘、圆盘式载物台，可以顺利完成车间作业中的物料搬运、码垛、自动循迹与避障等功能。

“泰迪”小车具有外观精巧、寻线稳定、转弯流畅、定位精准、容错率高等特点。

1） 电源与熔断器串联，防止电流过大烧毁电路元件；
2） 双开关设计，便于调试和启动；
3） 车体前方七路灰度传感器用以巡线以及定位；前侧两旁超声波传感器用以避障；
4） 中后部步进电机用以驱动载物台，定位精准；
5） 步进电机加速过程采用S型加速曲线，保证不失步；
6） 使用上下位机配合控制转盘，提高了模块化程度，减轻了上位机计算负担；
7） 小车上部三自由度机械臂用以抓取和放置物块；
8） 使用气动吸盘抓取物块，整体提高了速度和稳定性；
9） 小车中部的倾斜式储物架用以存储物料，提高了拿放物块时的容错率；

10）在扫描不成功时能够自动调整位置，使得上下物块时成功率更高。
| 作品说明 | 比 例
| 第五届浙江省大学生工程训练综合能力竞赛 | 共 5 页 | 第 1 页

装

订

线

学校名称：

第五届浙江省大学生工程训练综合能力竞赛 The 5th ZheJiang Undergraduate Engineering Training Integration Ability Competition | 结构设计方案 Structure Design Scheme | | 共 5 页 | 第 2 页
| | | 编 号 | （工作人员填写）


轴距轮距示意图

小车正面图

1、 机械结构设计思路

根根据比赛需要，小车结构分为移动、抓取和装载三个部分。移动部分提供小车的运动功能，抓取部分完成上下货，装载部分用于指定货物的选择。

1.1移动部分

移动部分由底板、电机、联轴器和轮胎组成，负责小车全部的运动功能。其中重难点包括电机的选型、底板的设计制造和电机在底板上的装配位置。

1）为保证小车有足够的驱动能力。移动方案采用四驱直排的设计，四个轮子皆为主动轮，保证在适当速率和一定承重条件下小车拥有足够的爬坡和转向能力。

2)小车主要通过降低小车重心的办法来提高整车稳定性。

a.设计方案中控制器、锂电池、稳压、驱动等电路模块都安装在底板下方

b.载物台使用空心轴承，便于将机械臂安装在载物台里面而不是上面，降低机械臂离地距离。

3)为减小小车转弯时的摩擦力。我们通过减小前后轮距、增大左右轮距的方法来减小小车转弯时的摩擦力。在电机底板设计时，将轮距定为163.77mm，轴距定为166.33mm。

1.2抓取部分

抓取部分由一个三自由度机械臂和气动吸盘组成，负责物料的抓取和放置。

1）为提高机械臂运动的稳定性及准确度。我们采用降低机械臂自由度的方法。但过低的自由度会使得机械臂不能顺利完成任务，因此我们采用三自由度机械臂。

2）为提高抓取及放置物块的成功率。

a.使用气动吸盘代替机械爪，气动吸盘占用空间少，方便拿放。

b.吸盘为30mm直径的双层海绵吸盘，相同吸力条件下较普通吸盘有更好的吸取效果。

1.3装载部分

装载部分由空心大轴承、步进电机、大小齿轮和六个储物架组成，小齿轮固定在步进电机输出轴上，大齿轮固定在空心轴承上，主要完成物料存储的功能。

1) 为使物块放置在储物架上时不发生左右晃动和翻倒的现象。

a. 储物架内底面与水平面的夹角为30度内壁有一定倾角。

b.储物架底座的长设置为58mm，宽为53mm，比物块50mm*50mm的底面稍大了一点。。

2)为提高物块放置时的容错率，储物架的挡板与竖直平面有15度的夹角。

3为提高载物台转动的准确性。我们采用小齿轮驱动大齿轮的方法，步进电机转动精度为1.8度，大小齿轮齿数比为5：1，理论上大齿轮的精度可达到0.36度。

4)为减少机械臂的动作组数量，降低机械臂调试难度。我们主要采用机械臂不转而载物台转动的方式。

学校名称：

装

订

线

第五届浙江省大学生工程训练综合能力竞赛 The 5th ZheJiang Undergraduate Engineering Training Integration Ability Competition | 结构设计方案 Structure Design Scheme | | 共 5 页 | 第 3 页
| | | 编 号 | （工作人员填写）


机械臂臂长参数 | | 2、小车机械臂设计方案 2.1总体设计 1）为降低机械臂的末端误差，方案决定采用满足需求的最少自由度数：三自由度，分别控制末端的位置和吸盘的方向。 2）为保证机械臂能够顺利够到物块，结合实际计算后设计机械臂长度174.200+149.200+69.738mm。 2.2舵机选用 1)机械臂靠近根部的第一、二个关节使用300度舵机，最远端使用探索者公司提供的180度舵机。由于金属舵盘和探索者套装零件尺寸不符，将重新钻孔使其配合。 2)为了避免出现打齿现象，所有将承受较大力矩的舵盘均选用金属舵盘。 3)为减轻最底端舵机的负担，使用两股由四根橡筋扭成的弹性结构将底座与第一段机械臂相连用于补偿力矩。 2.3吸盘设计 1)为避免一屋吸盘吸力不够和三屋吸盘容易晃动的问题抓取物块的部分采用两屋气动吸盘。 2)为提高吸盘吸取效果，在接触部分采用海绵材质，保证吸盘与对象的表面完全接触。
| | 3、总结和体会 “泰迪”小车的诞生，是我们整个小队团结合作的成果。在刚开始制作小车的过程中，我们一边借鉴前人的成果，一边努力学习机械结构的知识，并将之用于我们自己的小车上。我们团队间的工作分工比较明确，有人负责设计小车底板，有人负责设计物料架与大小齿轮，也有的负责设计机械臂以及气动吸盘。然后定期将各自的结果进行讨论，以此来改进结构的设计。改完之后再重复上述过程，就这样一步步逐渐优化小车整体的结构，才终于做成了我们的“泰迪”小车。 设计、制作与改进小车的过程是一次宝贵的理论与实际结合的经历。在整个过程中，我们不仅学习了知识，更学会了如何将自己所学用到实践中去，当然其中遇到了很多的曲折与错误，也有很多误解与分歧。最重要的是，在整个团队合作的过程中，我们锻炼了我们沟通与理解的能力，也开始了解到团队合作中责任的意义。

学校名称：

装

订

线


序号 | 名称 | 数量 | 序号 | 名称 | 数量 | 序号 | 名称 | 数量 | 序号 | 名称 | 数量
1 | 2S航模锂电池 | 1 | 9 | 电磁换向阀 | 3 | 17 | 吸盘支架 | 1 | 25 | 大电流电机驱动板 | 1
2 | Arduino nano | 1 | 10 | 气泵 | 1 | 18 | 舵机 | 3 | 26 | 直流降压板 | 1
3 | L298N双H桥驱动模块 | 2 | 11 | 载物台底座 | 6 | 19 | 舵机支架 | 3 | 27 | 舵机控制板 | 1
4 | 42步进电机 | 1 | 12 | 载物台挡板 | 12 | 20 | 长型支架 | 4 | 28 | Arduino mega2560 | 1
5 | 小齿轮 | 1 | 13 | 机械臂支架 | 1 | 21 | 电池挂载板 | 1 | 29 | JGB37-52电机 | 4
6 | 大齿轮 | 1 | 14 | U型支架 | 3 | 22 | 步进电机支架 | 1 | 30 | 电机连接板 | 4
7 | 超声波传感器 | 2 | 15 | 机械臂连接板 | 12 | 23 | 开关 | 1 | 31 | 底板 | 1
8 | 七路灰度传感器 | 1 | 16 | 二屋海绵气动吸盘 | 1 | 24 | 旋钮 | 1
| 小车装配图 | 比 例
| 第五届浙江省大学生工程训练综合能力竞赛 | 共 5 页 | 第 4 页

装

订

线

学校名称：


| 小车爆炸图 | 比 例
| 第五届浙江省大学生工程训练综合能力竞赛 | 共 5 页 | 第 5 页

装

订

线

学校名称：

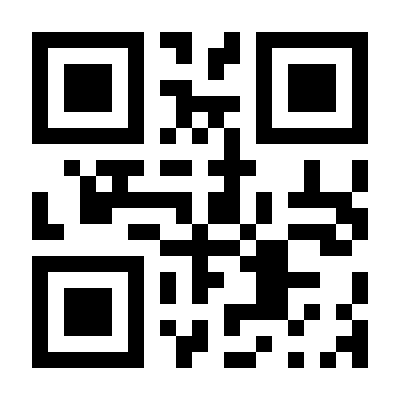
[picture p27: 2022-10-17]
123+321.png

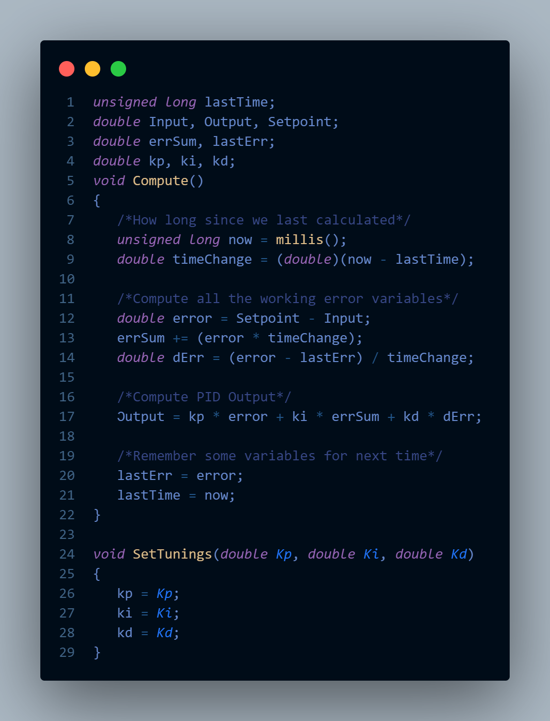
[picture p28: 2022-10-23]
方案文档/材料/PID.png

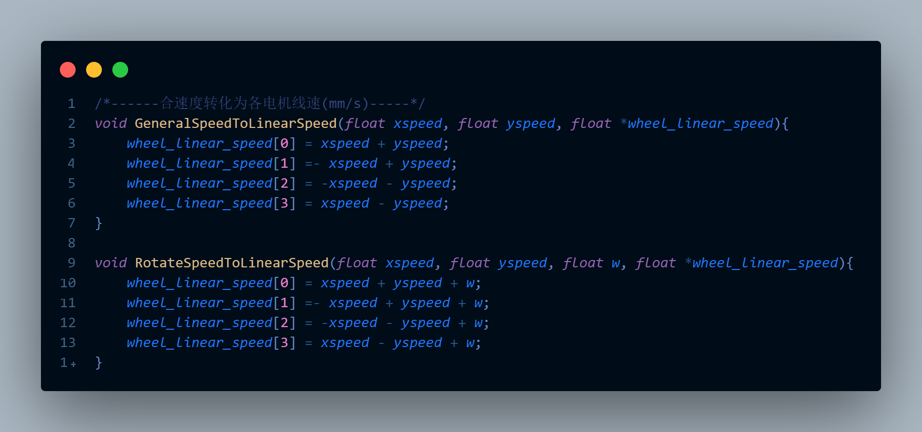
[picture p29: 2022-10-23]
方案文档/材料/速度分解.png

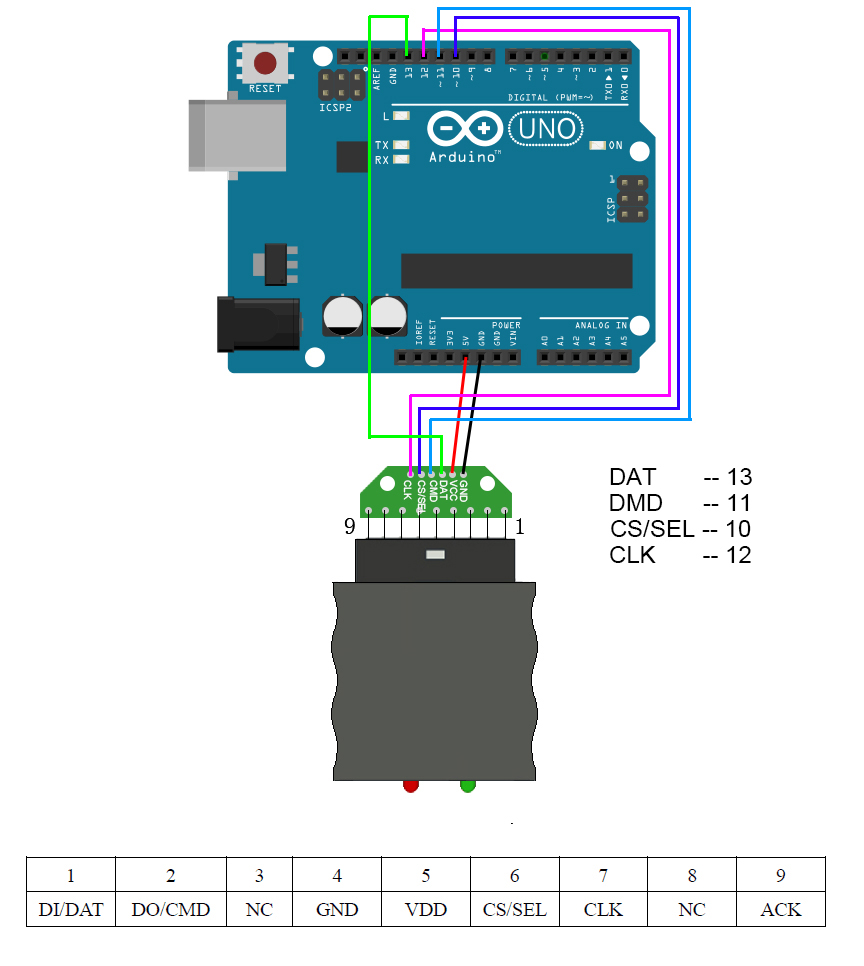
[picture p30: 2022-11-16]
PS2手柄 - arduino 资料/arduino+手柄接收器连接图.jpg

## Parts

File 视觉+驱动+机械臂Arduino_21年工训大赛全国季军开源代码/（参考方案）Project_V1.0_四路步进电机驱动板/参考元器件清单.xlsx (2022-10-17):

PCB所需元器件 | 规格 | tb链接(仅供参考) | 描述
直插电解电容 | 50v100uf | https://m.tb.cn/h.49QUW4V | 焊接时需注意正负极
直插电阻 | 10k 1/4w | https://m.tb.cn/h.4PFhj1G | 焊接时无所谓正负极
电源接线端子 5.0mm | 2p | https://m.tb.cn/h.49QeAKq | 其他接线端子 5mm的接线端子也可
排针 2.54mm | 40P | https://m.tb.cn/h.4P1WBGm | 2.54mm间距即可
5*20 保险座+保险丝 | 保险座*1+保险丝若干 | https://m.tb.cn/h.4PvgKFN | 可选3A\5A保险丝
插针座 | 8P | https://m.tb.cn/h.4kFxhxb | 插驱动模块
步进电机驱动模块 | A4988/DRV8825 | a4988约4块一个，drv8825约6块一个 | 推荐drv8825
Tips： | 驱动模块买来需调节一下电位计。

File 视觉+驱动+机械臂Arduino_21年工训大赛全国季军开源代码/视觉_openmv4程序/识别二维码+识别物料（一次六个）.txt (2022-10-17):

/********************************************
//  tips: 使用mega2560的硬件串口一与openmv进行通讯
//  参考文章： https://zhuanlan.zhihu.com/p/367614669
//  联系方式： 知乎 “Poao”
//                    2021/4/25  —— by Poao
**********************************************/

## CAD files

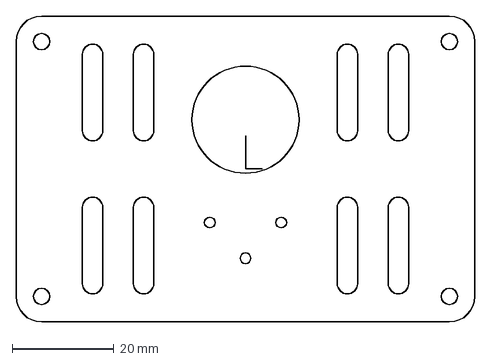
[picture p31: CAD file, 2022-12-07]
3D模型/机械臂底板.DXF
90.0 x 60.0 mm

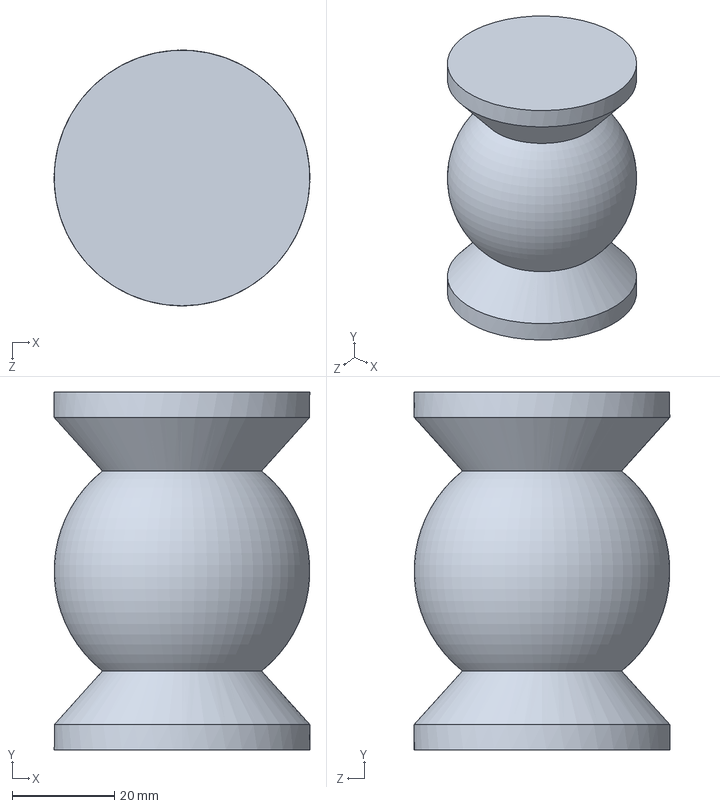
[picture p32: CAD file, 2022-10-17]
视觉+驱动+机械臂Arduino_21年工训大赛全国季军开源代码/物料模型和赛道图/2021-工训-Poao/物料/基础物料.SLDPRT
50.0 x 70.0 x 50.0 mm

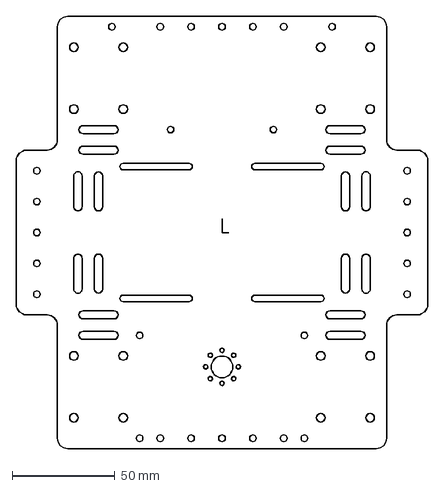
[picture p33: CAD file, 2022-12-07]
3D模型/底板.DXF
200.0 x 210.0 mm

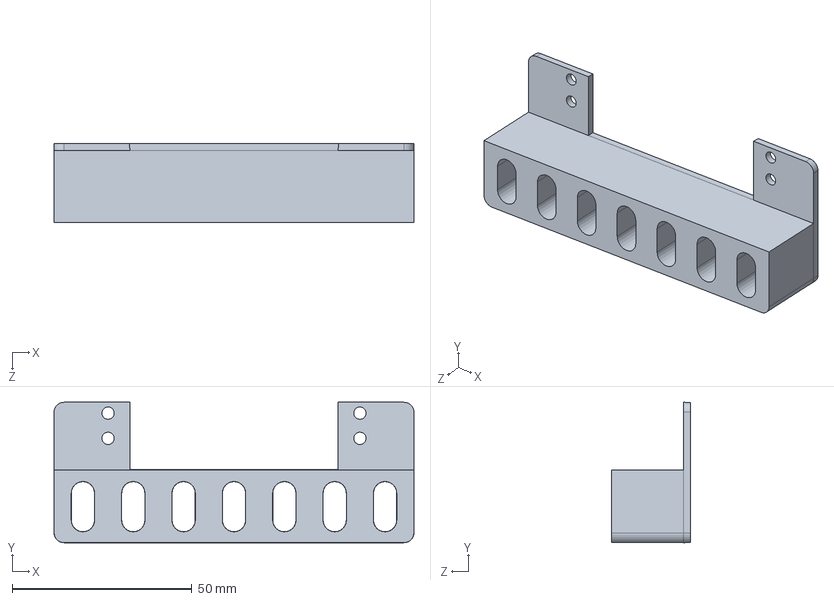
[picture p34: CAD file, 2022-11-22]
3D模型/7路灰度传感器支架.SLDPRT
100.1 x 39.1 x 22.0 mm

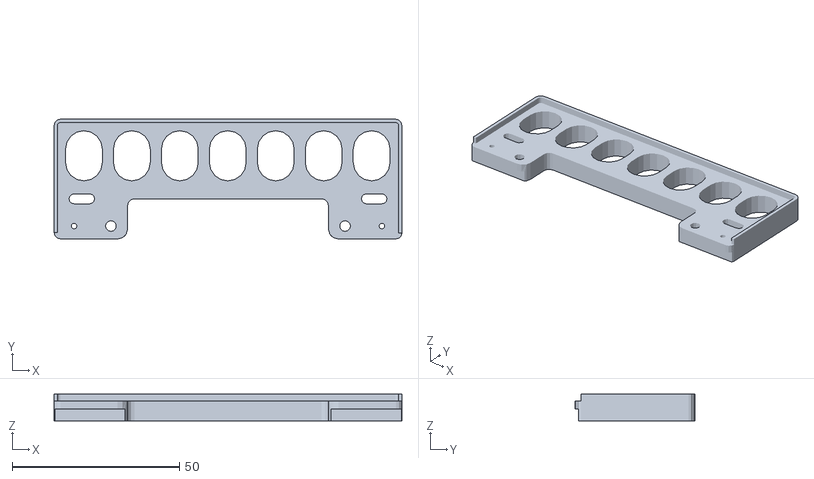
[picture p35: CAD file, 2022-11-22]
3D模型/7路保护架_参考设计.STL
104.0 x 35.8 x 8.00

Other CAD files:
方案文档/材料/底盘草图.dwg
视觉+驱动+机械臂Arduino_21年工训大赛全国季军开源代码/物料模型和赛道图/2021-工训-Poao/物料/wuliao(可直接3d打印).STL
3D模型/7路灰度传感器支架.STL

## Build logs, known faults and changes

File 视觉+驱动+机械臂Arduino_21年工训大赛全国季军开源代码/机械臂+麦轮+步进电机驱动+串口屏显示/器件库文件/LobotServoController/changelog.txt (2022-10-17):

TIME:201608311120
DESCRIPTION:在Arduino Leonardo 中Serial保留，用于USB CDC设备。板上RX和TX为Serial1，所以将Leonardo等板子默认串口修改为Serial1

TIME:201607082007
DESCRIPTION:为在Arduino Mega 等具有多个硬件串口的设备上切换串口，去除静态方法

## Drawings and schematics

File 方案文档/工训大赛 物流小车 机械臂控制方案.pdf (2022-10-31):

# 工训大赛 | 物流小车 | 机械臂控制方案

# 1. 起点

机械臂自然折叠状态

# 2. 起点到原料区

机械臂由折叠到自然展开

此处自然展开即为环节3的“中立位”

# 3. 原料区

1. 解算位置信息
2. 控制动作
3. 抓取货架上的物料时需遵循任务码顺序，放置到储物槽时需遵循色环的顺序

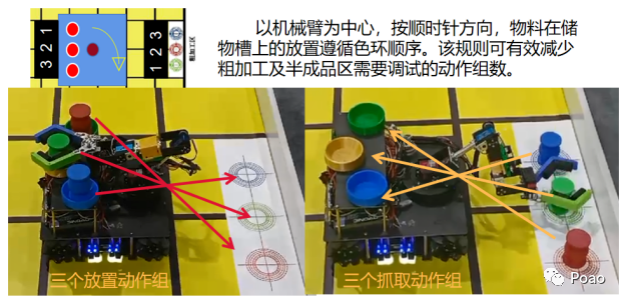
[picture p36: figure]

## 1. 设计动作组

### ① 抓取物料

3

三个位置抓取动作

### ② 放置物料

3

三个位置放置动作

### ③ 到中立位

1

回位动作

No. 1 / 4

## 2. 动作组顺序

# 4. 原料区到粗加工区

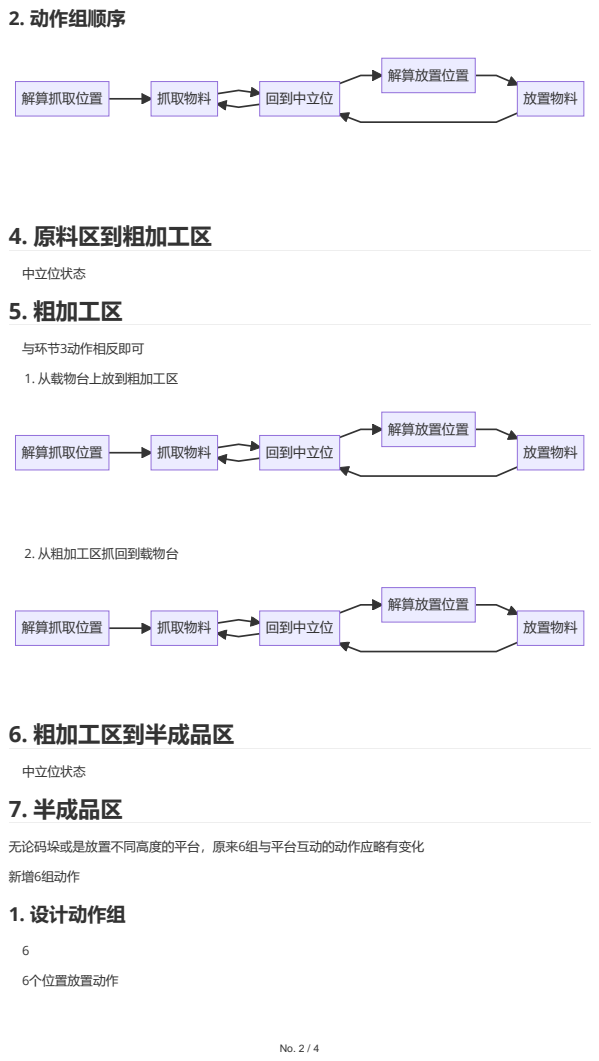
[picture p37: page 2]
解算抓取位置; 抓取物料; 回到中立位; 解算放置位置; 放置物料; 中立位状态 5. 粗加工区; 与环节3动作相反即可; 1. 从载物台上放到粗加工区; 2. 从粗加工区抓回到载物台; 6. 粗加工区到半成品区; 中立位状态 7. 半成品区; 无论码垛或是放置不同高度的平台，原来6组与平台互动的动作应略有变化; 新增6组动作 1. 设计动作组; 6个位置放置动作

# 8. 循环

# 9. 半成品区到终点

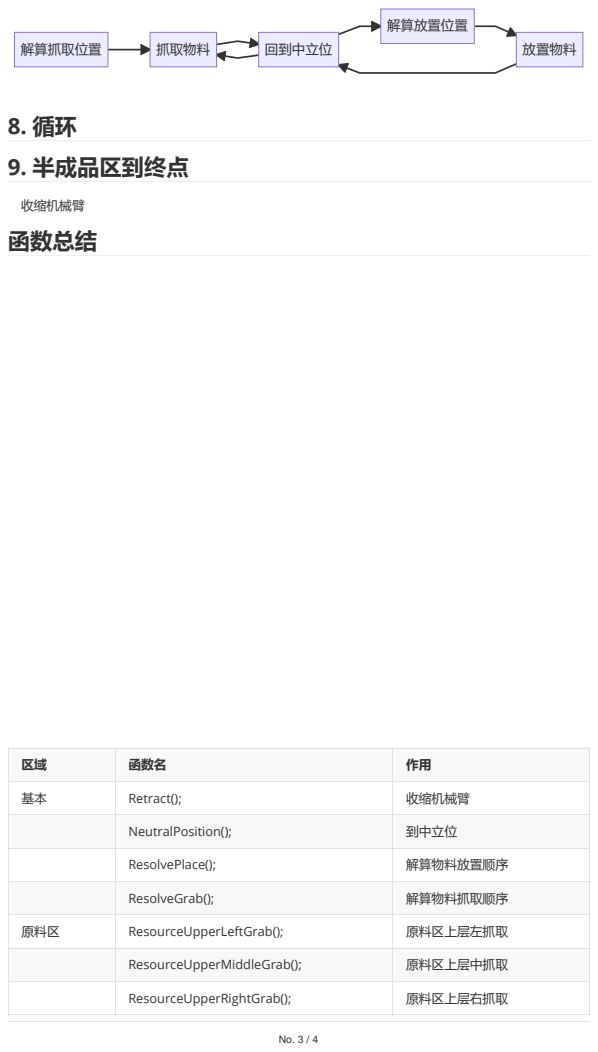
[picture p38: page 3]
解算抓取位置; 抓取物料; 回到中立位; 解算放置位置; 放置物料; 收缩机械臂 函数总结

区域 | 函数名 | 作用

基本 | Retract(); | 收缩机械臂

NeutralPosition(); | 到中立位

ResolvePlace(); | 解算物料放置顺序

ResolveGrab(); | 解算物料抓取顺序

原料区 | ResourceUpperLeftGrab(); | 原料区上层左抓取

ResourceUpperMiddleGrab(); | 原料区上层中抓取

ResourceUpperRightGrab(); | 原料区上层右抓取

区域 | 函数名 | 作用
| ResourceLowerLeftGrab(); | 原料区下层左抓取
| ResourceLowerMiddleGrab(); | 原料区下层中抓取
| ResourceLowerRightGrab(); | 原料区下层右抓取
| StageLeftPlace(); | 载物台左放置
| StageMiddlePlace(); | 载物台中放置
| StageRightPlace(); | 载物台右放置
粗加工区 | StageLeftGrab(); | 载物台左抓取
| StageMiddleGrab(); | 载物台中抓取
| StageRightGrab(); | 载物台右抓取
| RoughLeftPlace(); | 粗加工区左放置
| RoughMiddlePlace(); | 粗加工区中放置
| RoughRightPlace(); | 粗加工区右放置
半成品区 | UpperLeftPlace(); | 半成品区上层左放置
| UpperMiddlePlace(); | 半成品区上层中放置
| UpperRightPlace(); | 半成品区上层右放置
| LowerLeftPlace(); | 半成品区下层左放置
| LowerMiddlePlace(); | 半成品区下层中放置
| LowerRightPlace(); | 半成品区下层右放置

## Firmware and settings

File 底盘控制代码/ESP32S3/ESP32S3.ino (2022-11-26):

#include <Ticker.h>     //定时中断
#include "OOPConfig.h"  //包含配置库
#include <U8g2lib.h>    //包含OLED库
#include "ESP32Car.h"
#include "I2Cdev.h"
#include "MPU6050_6Axis_MotionApps_V6_12.h"
#if I2CDEV_IMPLEMENTATION == I2CDEV_ARDUINO_WIRE
#include "Wire.h"
#include <math.h>
#endif

// #include "SunGrayscale_b.h"

#ifndef DEBUG_INFO
#define DEBUG_INFO
#endif
#ifndef BAUDRATE
#define BAUDRATE 115200
#endif

#define TARPULSE 30
#define ADJUSTPLSE 20
#define XP 1
#define XI 0.01
#define XD 0.1
#define YP 1.5
#define YI 0.01
#define YD 0.01
#define AP 1
#define AI 0.01
#define AD 0.01
#define KX 7

int stage = 0, waitcount = 0, waittar = 0, waitopen = 0;
int linepatrol_on = 0, linecount = 0, linetar = 0, microtimer = 0;
int turn_on = 0;
int adjust_on = 0;
void MapRunning(void);

MPU6050 mpu;
// MPU control/status vars
bool dmpReady = false;   // set true if DMP init was successful如果dmp设置为真则设置为true
uint8_t mpuIntStatus;    // holds actual interrupt status byte from MPU
uint8_t devStatus;       // return status after each device operation (0 = success,
                         // !0 = error)
uint16_t packetSize;     // expected DMP packet size (default is 42 bytes)
uint16_t fifoCount;      // count of all bytes currently in FIFO
uint8_t fifoBuffer[64];  // FIFO storage buffer FIFO存储缓存区

// orientation/motion vars
Quaternion q;    // [w, x, y, z]         quaternion container
VectorInt16 aa;  // [x, y, z]            accel sensor measurements
VectorInt16 gy;  // [x, y, z]            gyro sensor measurements
VectorInt16
  aaReal;  // [x, y, z]            gravity-free accel sensor measurements
VectorInt16
  aaWorld;            // [x, y, z]            world-frame accel sensor measurements
VectorFloat gravity;  // [x, y, z]            gravity vector
float
  ypr[3];  // [yaw, pitch, roll]   yaw/pitch/roll container and gravity vector

void MPU6050_Init(void);
float raw_yaw = 0, tar_yaw = 0;
int raw_yaw_flag = 0;

// OLED配置esp32引脚映射
U8G2_SSD1306_128X64_NONAME_F_HW_I2C u8g2(U8G2_R0, U8X8_PIN_NONE, SCL, SDA);  // ESP32 Thing, HW I2C with pin remapping
void OLED_Init(void);
void OLED_Print(String x);

float xspeed = 0, yspeed = 0, angular_velocity = 0;
float X_SUM = 0, Y_SUM = 0, A_SUM = 0;
float x_offset = 0, y_offset = 0, a_offset = 0;

//灰度传感器函数
Grayscale GraySensors;
Grayscale_b GraySensors_b;
// uart输出量的结构体
Grayscale::strOutput GrayUartOutputIO;
Grayscale_b::strOutput_b GrayUartOutputIO_b;
// 中断函数
Ticker timer1;
bool timer_flag = 0;

// 创建4个编码器实例
SunEncoder ENC[WHEELS_NUM] = {
  SunEncoder(M1ENA, M1ENB), SunEncoder(M2ENA, M2ENB),
  SunEncoder(M3ENA, M3ENB), SunEncoder(M4ENA, M4ENB)
};

long targetpulse[WHEELS_NUM] = { 0, 0, 0, 0 };     //四个车轮的目标计数
long feedbackPulses[WHEELS_NUM] = { 0, 0, 0, 0 };  //四个车轮的10ms定时中断编码器四倍频计数
double outPWM[WHEELS_NUM] = { 0, 0, 0, 0 };        //输出PWM值

// PID参数设置
float Kp = 10, Ki = 0.1, Kd = 0;
float P, I, D;
PID VeloPID[WHEELS_NUM] = {
  PID(PWM_MIN, PWM_MAX, Kp, Ki, Kd), PID(PWM_MIN, PWM_MAX, Kp, Ki, Kd),
  PID(PWM_MIN, PWM_MAX, Kp, Ki, Kd), PID(PWM_MIN, PWM_MAX, Kp, Ki, Kd)
};

// 创建1个4路电机对象
BDCMotor motors;

typedef struct grayscaledata {
  uint8_t lf, lm, lb, rf, rm, rb;
  int8_t translation_error = 0,  // 旋转偏差: 逆时针偏角为正，顺时针偏角为负，取值
    rotation_error = 0;          // 平动(左右)偏差: 正为偏前，负为偏后，取值-2~2
  uint8_t unknowncase;
} GrayscaleDataType;

GrayscaleDataType GrayscaleData;

int n = 0, flag = 0;
int8_t begin, end;
uint8_t direction = 0;  // 运功方向0:不动,1:x轴,2:y轴

// 电机函数
void MotorSpeeds(int m1, int m2, int m3, int m4);
void Forward_Move(int targetpulse);
void Backward_Move(int targetpulse);
void Left_Move(int targetpulse);
void Right_Move(int targetpulse);
// void Left_Turn(int angle);
void Right_Turn(int angle);
void Turn_Callback(void);
void Line_Patrol(void);  // 巡线
void Line_Patrol_y(void);
void PID_Static_Adjust(void);
void X_Adjust(void);
void Y_Adjust(void);
void Z_Adjust(void);
void U8G2_Print(void);
void WaitCallback(void);
void Wait(int time);


void setup() {
  OLED_Init();
  Serial.begin(BAUDRATE);
  Chassis_Init();
  MPU6050_Init();
  delay(2000);
  // Right_Turn(90);
}
uint8_t flag_MPU = 0;
void loop() {
  MPU6050_Read();
  U8G2_Print();
  MapRunning();
}

void MapRunning() {

  switch (stage) {
    case 0: Wait(500); break;
    case 1: Line_Patrol_on(3); break;
    case 2: Wait(500); break;
    case 3: Static_Adjust_on(); break;
    case 4: Wait(500); break;
    case 5: Right_Turn(90); stage++; break;
    case 6: Wait(2000); break;
    case 7: Static_Adjust_on(); break;
    case 8: Wait(500); break;
    case 9: Line_Patrol_on(2); break;
    case 10: Wait(500); break;
    case 11: Static_Adjust_on(); break;
    case 12: Wait(500); break;
    case 13: Right_Turn(90); stage++; break;
    case 14: Wait(2000); break;
    case 15: Static_Adjust_on(); break;
    case 16: Wait(500); break;
    case 17: Line_Patrol_on(3); break;
    case 18: Wait(500); break;
    case 19: Static_Adjust_on(); break;
    case 20: Wait(500); break;
    case 21: Right_Turn(90); stage++; break;
    case 22: Wait(2000); break;
    case 23: Static_Adjust_on(); break;
    case 24: Wait(500); break;
    case 25: Line_Patrol_on(2); break;
    case 26: Wait(500); break;
    case 27: Static_Adjust_on(); break;
    case 28: Wait(500); break;
    case 29: Right_Turn(90); stage++; break;
    case 30: Wait(2000); break;
    case 31: Static_Adjust_on(); break;
    case 32: Wait(500); break;
      // case 3: Right_Turn(-90);break;
      // case 4: Wait(2000);

    default: break;
  }
}

void Wait(int time) {
  waitopen = 1;
  waittar = time / 10;
  if (waitcount > waittar) {
    stage++;
    waitopen = 0;
  }
}

void WaitCallback(void) {
  if (waitopen) waitcount++;
  else waitcount = 0;
}

void U8G2_Print(void) {
  u8g2.clearBuffer();                  // clear the internal memory
  u8g2.setFont(u8g2_font_ncenB12_tf);  // choose a suitable font
  u8g2.setCursor(0, 16);

  u8g2.print("x_offset:");
  u8g2.print(x_offset);
  // u8g2.print("  rf");
  // u8g2.print(GrayscaleData.rf);
  u8g2.setCursor(0, 32);
  u8g2.print("y_offset:");
  u8g2.print(y_offset);
  // u8g2.print("  rm");
  // u8g2.print(GrayscaleData.rm);
  u8g2.setCursor(0, 48);
  u8g2.print("a_offset:");
  u8g2.print(a_offset);
  // u8g2.print("  rb");
  // u8g2.print(GrayscaleData.rb);
  u8g2.setCursor(0, 64);
  // u8g2.print("D:");
  // u8g2.print(D);
  u8g2.print("stage:");
  u8g2.print(stage);
  // u8g2.print("  re");
  // u8g2.print(GrayscaleData.rotation_error);

  u8g2.sendBuffer();
}

void Chassis_Init(void) {
  motors.init();
  motors.map2model(1, 2, 3, 4);                                                   //映射实际接线电机编号到理论建模编号，默认顺序1，2，3，4
  motors.flipMotors(FLIP_MOTOR[0], FLIP_MOTOR[1], FLIP_MOTOR[2], FLIP_MOTOR[3]);  // 需修改 OOPConfig.h 设置为绿色尾部电机参数
  motors.setSpeeds(0, 0, 0, 0);
  for (int i = 0; i < WHEELS_NUM; i++) {
    ENC[i].init();
    ENC[i].flipEncoder(FLIP_ENCODER[i]);
  }
  GrayscaleData.rotation_error = GrayscaleData.translation_error = 0;
  timer1.attach_ms(TIMER_PERIOD, timerISR);  // 打开定时器中断

  // attachInterrupt(44,UART_Receive,CHANGE);
  interrupts();  //打开外部中断
}

//定时器中断处理函数,其功能主要为了输出编码器得到的数据
void timerISR() {
  // raw_yaw_flag = 2;
  UART_Receive();
  GrayUartOutputIO = GraySensors.readUart();  //读取串口数字量数据
  GrayUartOutputIO_b = GraySensors_b.readUart_b();
  WaitCallback();
  PID_Static_Adjust();
  Line_Patrol();
  Turn_Callback();
  Velocity_Transform();

  //获取电机脉冲数（速度）
  timer_flag = 1;  //定时时间达到标志
  for (int i = 0; i < WHEELS_NUM; i++) {
    feedbackPulses[i] = ENC[i].read();

    ENC[i].write(0);  //复位
    outPWM[i] = VeloPID[i].Compute(targetpulse[i], feedbackPulses[i]);
  }
  motors.setSpeeds(outPWM[0], outPWM[1], outPWM[2], outPWM[3]);
}


void UART_Receive(void) {
  if ((flag = Serial.available()) >= 11) {
    begin = Serial.read();
    GrayscaleData.lf = Serial.read();
    GrayscaleData.lm = Serial.read();
    GrayscaleData.lb = Serial.read();
    GrayscaleData.rf = Serial.read();
    GrayscaleData.rm = Serial.read();
    GrayscaleData.rb = Serial.read();

    GrayscaleData.translation_error = Serial.read();
    GrayscaleData.rotation_error = Serial.read();
    GrayscaleData.translation_error = -GrayscaleData.lf + GrayscaleData.lb - GrayscaleData.rf + GrayscaleData.rb;
    GrayscaleData.rotation_error = GrayscaleData.lf - GrayscaleData.lb - GrayscaleData.rf + GrayscaleData.rb;
    GrayscaleData.unknowncase = Serial.read();

    end = Serial.read();
    // flag = 1;
    while (Serial.read() >= 0) {}
  }
}

// OLED打印函数
void OLED_Init(void) {
  u8g2.begin();
  u8g2.enableUTF8Print();
  u8g2.clearBuffer();               // clear the internal memory
  u8g2.setFont(u8g2_font_7x14_tf);  // choose a suitable font
  u8g2.setCursor(0, 16);
  u8g2.println("E-Revenger");
  u8g2.setCursor(0, 16);
  u8g2.sendBuffer();
}

// void OLED_Print(String x) {
//   u8g2.println(x);
//   u8g2.setCursor(0, 16);
//   u8g2.sendBuffer();
// }

void Velocity_Transform(void) {
  targetpulse[0] = int(xspeed - yspeed - angular_velocity);
  targetpulse[1] = int(xspeed + yspeed + angular_velocity);
  targetpulse[2] = int(xspeed + yspeed - angular_velocity);
  targetpulse[3] = int(xspeed - yspeed + angular_velocity);
}

void MotorSpeeds(int m1, int m2, int m3, int m4) {
  targetpulse[0] = m1;
  targetpulse[1] = m2;
  targetpulse[2] = m3;
  targetpulse[3] = m4;
}

void Forward_Move(int targetpulse) {
  MotorSpeeds(targetpulse, targetpulse, targetpulse, targetpulse);
}

void Backward_Move(int targetpulse) {
  MotorSpeeds(-targetpulse, -targetpulse, -targetpulse, -targetpulse);
}

void Left_Move(int targetpulse) {
  MotorSpeeds(-targetpulse, targetpulse, targetpulse, -targetpulse);
}

void Right_Move(int targetpulse) {
  MotorSpeeds(targetpulse, -targetpulse, -targetpulse, targetpulse);
}

void Right_Turn(int angle) {
  raw_yaw_flag = 1;
  tar_yaw = ypr[0] * 180 / M_PI + angle < 180 ? ypr[0] * 180 / M_PI + angle : ypr[0] * 180 / M_PI + angle - 360;
}

void Turn_Callback(void) {
  if (raw_yaw_flag) {
    // raw_yaw_flag ++;
    a_offset = -(tar_yaw - ypr[0] * 180 / M_PI);
    if (a_offset > 180) {
      a_offset -= 360;
    } else if (a_offset < -180) {
      a_offset += 360;
    }
    A_Adjust();
    if (abs(a_offset) < 5) {
      raw_yaw_flag = 0;
      a_offset = 0;
      stage++;
    }
  }
}

void Normal_Stop() {
  MotorSpeeds(0, 0, 0, 0);
}

void Brake_Stop() {
  brake();
}

void CalculateOffset(void) {
  x_offset = (KX * GrayscaleData.translation_error);
  y_offset = (GrayUartOutputIO.offset - GrayUartOutputIO_b.offset_b) < 100 ? GrayUartOutputIO.offset - GrayUartOutputIO_b.offset_b : 0;
  if (direction == 0) a_offset = 0.6 * (-(GrayUartOutputIO.offset + GrayUartOutputIO_b.offset_b) < 100 ? -GrayUartOutputIO.offset - GrayUartOutputIO_b.offset_b : 0) + 0.4 * KX * GrayscaleData.rotation_error;
  else if (direction == 1) a_offset = -(GrayUartOutputIO.offset + GrayUartOutputIO_b.offset_b) < 100 ? -GrayUartOutputIO.offset - GrayUartOutputIO_b.offset_b : 0;
  else a_offset = KX * GrayscaleData.rotation_error;
}

void Line_Patrol_on(int n) {
  linepatrol_on = 1;
  linetar = n;
  if (linecount >= linetar) {
    // Brake_Stop();
    stage++;
    linepatrol_on = 0;
    xspeed = yspeed = angular_velocity = 0;
  }
}

void Line_Patrol(void) {
  if (linepatrol_on) {
    direction = 1;
    xspeed = 20;
    CalculateOffset();
    Y_Adjust();
    A_Adjust();
    microtimer++;
    if (microtimer >= 30) {
      if ((!GrayscaleData.lf || !GrayscaleData.lm || !GrayscaleData.lb) && (!GrayscaleData.rf || !GrayscaleData.rm || !GrayscaleData.rb)) {
        linecount++;
        microtimer = 0;
      }
     
    }
  } else {
    linecount = 0;
    microtimer = 0;
  }
}

void Line_Patrol_y(void) {
  direction = 2;
  yspeed = 40;
  CalculateOffset();
  X_Adjust();
  A_Adjust();
}

void Static_Adjust_on(void){
  adjust_on = 1;
}

void PID_Static_Adjust(void) {
  if(adjust_on){
    direction = 0;
    CalculateOffset();
    X_Adjust();
    Y_Adjust();
    A_Adjust();
    if(!x_offset&&!y_offset&&!a_offset){
      adjust_on = 0;
      stage++;
      xspeed = yspeed = angular_velocity = 0;
    }
  }  
}

void X_Adjust(void) {
  float error = x_offset;
  float P, I, D;
  if (X_SUM < 20 / XI) X_SUM += error;
  P = XP * error;
  I = XI * X_SUM > 10 ? XI * X_SUM : 0;
  D = XD * (error - x_offset);
  x_offset = error;
  xspeed = P + I + D < 30 ? P + I + D : 30;
}

void Y_Adjust(void) {
  float error = y_offset;
  static int flag = 0;
  flag++;
  float P, I, D;
  if (Y_SUM < 20 / YI) Y_SUM += error;
  P = YP * error;
  I = YI * Y_SUM > 10 ? YI * Y_SUM : 0;
  D = YD * (error - y_offset);
  y_offset = error;
  yspeed = P + I + D < 30 ? P + I + D : 30;
}

void A_Adjust(void) {
  float error = a_offset;
  // float P, I, D;
  if (A_SUM < 20 / AI) A_SUM += error;
  P = AP * error;
  I = AI * A_SUM > 7 ? AI * A_SUM : 0;
  D = AD * (error - a_offset);
  a_offset = error;
  angular_velocity = P + I + D < 30 ? P + I + D : 30;
}

void MPU6050_Init(void) {
  // join I2C bus (I2Cdev library doesn't do this automatically)
#if I2CDEV_IMPLEMENTATION == I2CDEV_ARDUINO_WIRE
  Wire.begin();
  Wire.setClock(400000);  // 400kHz I2C clock. Comment this line if having
                          // compilation difficulties
#elif I2CDEV_IMPLEMENTATION == I2CDEV_BUILTIN_FASTWIRE
  Fastwire::setup(400, true);
#endif

  // initialize serial communication
  // (115200 chosen because it is required for Teapot Demo output, but it's
  // really up to you depending on your project)
  Serial.begin(115200);
  while (!Serial)
    ;  // wait for Leonardo enumeration, others continue immediately

  // NOTE: 8MHz or slower host processors, like the Teensy @ 3.3V or Arduino
  // Pro Mini running at 3.3V, cannot handle this baud rate reliably due to
  // the baud timing being too misaligned with processor ticks. You must use
  // 38400 or slower in these cases, or use some kind of external separate
  // crystal solution for the UART timer.

  // initialize device
  Serial.println(F("Initializing I2C devices..."));
  mpu.initialize();

  // verify connection
  Serial.println(F("Testing device connections..."));
  Serial.println(mpu.testConnection() ? F("MPU6050 connection successful")
                                      : F("MPU6050 connection failed"));

  // load and configure the DMP
  Serial.println(F("Initializing DMP..."));
  devStatus = mpu.dmpInitialize();

  // supply your own gyro offsets here, scaled for min sensitivity
  //提供陀螺仪的偏移量，运行IMU_Zero获得后输入OOPConfg.h
  mpu.setXAccelOffset(XAccelOffset);
  mpu.setYAccelOffset(YAccelOffset);
  mpu.setZAccelOffset(ZAccelOffset);
  mpu.setXGyroOffset(XGyroOffset);
  mpu.setYGyroOffset(YGyroOffset);
  mpu.setZGyroOffset(ZGyroOffset);
  // make sure it worked (returns 0 if so)
  if (devStatus == 0) {
    // Calibration Time: generate offsets and calibrate our MPU6050
    mpu.CalibrateAccel(6);
    mpu.CalibrateGyro(6);
    Serial.println();
    mpu.PrintActiveOffsets();
    // turn on the DMP, now that it's ready
    Serial.println(F("Enabling DMP..."));
    mpu.setDMPEnabled(true);

    dmpReady = true;

    // get expected DMP packet size for later comparison
    packetSize = mpu.dmpGetFIFOPacketSize();
  } else {
    // ERROR!
    // 1 = initial memory load failed
    // 2 = DMP configuration updates failed
    // (if it's going to break, usually the code will be 1)
    Serial.print(F("DMP Initialization failed (code "));
    Serial.print(devStatus);
    Serial.println(F(")"));
  }
}

void MPU6050_Read(void) {
  // if programming failed, don't try to do anything
  if (!dmpReady) {
    flag_MPU = 1;
    return;
  }
  // read a packet from FIFO
  if (mpu.dmpGetCurrentFIFOPacket(fifoBuffer)) {  // Get the Latest packet

    // display Euler angles in degrees
    mpu.dmpGetQuaternion(&q, fifoBuffer);
    mpu.dmpGetGravity(&gravity, &q);
    mpu.dmpGetYawPitchRoll(ypr, &q, &gravity);
    // Serial.print("yaw\t");
    // Serial.print(ypr[0] * 180 / M_PI);
    // Serial.println();
    mpu.dmpGetGyro(&gy, fifoBuffer);
    // Serial.print("Raw Gyro XYZ\t");
    // Serial.print(gy.x);
    // Serial.print("\t");
    // Serial.print(gy.y);
    // Serial.print("\t");
    // Serial.print(gy.z);
    // Serial.println();
  }
}

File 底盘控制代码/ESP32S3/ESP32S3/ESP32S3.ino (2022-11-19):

#include "ESP32Car.h"
#include <math.h>
#include "PS2X_lib.h"
#include "pins_ESP32S3YD.h"
#include <Ticker.h>
#include "OOPConfig.h"

/******************全局初始化***************************/
#define BAUD 115200
void E_Revenger_Init(void);

/******************电机控制***************************/
void Chassis_Init(void);
int motospeed[4] = {0,0,0,0},
    xspeed = 0,
    yspeed = 0,
    angle_speed = 0;
void RotateSpeedToLinearSpeed(int xspeed, int yspeed, int w,int *wheel_linear_speed);
/************************* PID ****************************/
#define TARGET_PULSES long(COUNTS_PER_10MS/2)

//创建4个编码器实例
SunEncoder ENC[WHEELS_NUM] = {
    SunEncoder(M1ENA, M1ENB), SunEncoder(M2ENA, M2ENB),
    SunEncoder(M3ENA, M3ENB), SunEncoder(M4ENA, M4ENB)};


long targetPulses[WHEELS_NUM] = {TARGET_PULSES, TARGET_PULSES, TARGET_PULSES, TARGET_PULSES};  //四个车轮的目标计数
long feedbackPulses[WHEELS_NUM] = {0, 0, 0, 0};  //四个车轮的10ms定时中断编码器四倍频计数
double outPWM[WHEELS_NUM] = {0, 0, 0, 0};//输出PWM值

//创建4个速度PID实例
/*PID(float min_val, float max_val, float kp, float ki, float kd)
 * float min_val = min output PID value
 * float max_val = max output PID value
 * float kp = PID - P constant PID控制的比例、积分、微分系数
 * float ki = PID - I constant
 * float di = PID - D constant
 * Input	(double)输入参数feedbackPulses，待控制的量
 * Output	(double)输出参数outPWM，指经过PID控制系统的输出量
 * Setpoint	(double)目标值targetPulses，希望达到的数值
 */
#ifdef USE_12V366RPM13PPR30_MOTOR
float Kp = 10, Ki = 0.1, Kd = 0;
#endif

#ifdef USE_12V333RPM11PPR30_MOTOR
float Kp = 10, Ki = 0.1, Kd = 0;
#endif

#ifdef USE_12V366RPM500PPR30_MOTOR
float Kp = 0.5, Ki = 0.01, Kd = 0;
#endif
PID VeloPID[WHEELS_NUM] = {
    PID(PWM_MIN, PWM_MAX, Kp, Ki, Kd), PID(PWM_MIN, PWM_MAX, Kp, Ki, Kd),
    PID(PWM_MIN, PWM_MAX, Kp, Ki, Kd), PID(PWM_MIN, PWM_MAX, Kp, Ki, Kd)};

//*****************创建1个4路电机对象***************************//
BDCMotor motors;

int print_Count = 0;

/******************编码器***************************/
#define FIXENCODER1 1
#define FIXENCODER2 0
#define FIXENCODER3 1
#define FIXENCODER4 0
#define WHEELS_NUM 4
// #define COUNTS_PER_REV 1560  // wheel encoder's num of ticks per rev 390*4=1560

float Velocity[WHEELS_NUM];  //电机速度
int SpeedPWM[WHEELS_NUM];
bool fixEncoder[WHEELS_NUM];  //编码器计数方向修正，0不需要修正,1需要修正


void Encoder_Init(void);

/******************时钟中断***************************/

#define MYIRTIME 10  // 自定义中断时间，单位ms，只能是10ms的整数倍

Ticker timer1;                          // 中断函数
const unsigned int interruptTime = 10;  // 中断时间
unsigned int printCount = 0;            // 中断时间
int timer_flag = 0;                     //定时器标志；

unsigned long lastTime = 0;
int millisecond = 0, mytimer_flag = 0;  // millisecond 范围0~9999

//定时器中断处理函数,得到编码器采样周期内的计数并清零
void timerIsr(void);
void CheckTimInterupt(int tim);
void PeriodElapsedCallback(int tim);

/******************遥控器***************************/
// pin 15 HIGH使用遥控器，LOW不使用
// pin 16 有无动静
// pin 18 前进后退 LOW 前进， HIGH 后退
// pin 17 左右 LOW 左， HIGH 右
#define WHETHER_USE_REMOTE_CONTROL 1  // 1 开启遥控, 0 不开启遥控
#define PS2_DAT 13                    //MISO
#define PS2_CMD 11                    //MOSI
#define PS2_SEL 10                    //SS
#define PS2_CLK 12                    //SLK

#define RC_ON HIGH
#define RC_OFF LOW



void PS2_Init(void);
void RemoteControlRead(void);
void RemoteControlDelay(int tim);

//#define pressures   true
#define pressures false
//#define rumble      true
#define rumble false

PS2X ps2x;  // create PS2 Controller Class
int error = 0;
byte type = 0;
byte vibrate = 0;
int rc_flag = 0;

// main
void setup(void) {
  E_Revenger_Init();
}
void loop(void) {
}

//函数定义
/******************全局***************************/
void E_Revenger_Init(void) {
  IR_Init();
  Serial.begin(BAUD);
  Encoder_Init();
  Chassis_Init();
  // PS2_Init();
  Init_timerIsr();
}
/******************底盘***************************/
void Chassis_Init(void) {
  pinMode(M1PWM1, OUTPUT);
  pinMode(M1PWM2, OUTPUT);
  pinMode(M2PWM1, OUTPUT);
  pinMode(M2PWM2, OUTPUT);
  pinMode(M3PWM1, OUTPUT);
  pinMode(M3PWM2, OUTPUT);
  pinMode(M4PWM1, OUTPUT);
  pinMode(M4PWM2, OUTPUT);
}

void RotateSpeedToLinearSpeed(int xspeed, int yspeed, int w,int *wheel_linear_speed){
  // 转动模式
	// wheel_linear_speed[0] = -xspeed + yspeed + w;
	// wheel_linear_speed[1] =  xspeed + yspeed + w;
	// wheel_linear_speed[2] = -xspeed - yspeed + w;
	// wheel_linear_speed[3] =  xspeed - yspeed + w;
  // 平动模式
	wheel_linear_speed[0] = -xspeed + yspeed + w;
	wheel_linear_speed[1] =  xspeed + yspeed + w;
	wheel_linear_speed[2] = -xspeed + yspeed + w;
	wheel_linear_speed[3] =  xspeed + yspeed + w;
}
/******************编码器***************************/
void Encoder_Init(void) {
  // IO引脚初始化
  pinMode(M1ENA, INPUT_PULLUP);
  pinMode(M1ENB, INPUT_PULLUP);
  pinMode(M2ENA, INPUT_PULLUP);
  pinMode(M2ENB, INPUT_PULLUP);
  pinMode(M3ENA, INPUT_PULLUP);
  pinMode(M3ENB, INPUT_PULLUP);
  pinMode(M4ENA, INPUT_PULLUP);
  pinMode(M4ENB, INPUT_PULLUP);

  attachInterrupt(M1ENA, readM1EncoderA,
                  CHANGE);  //中断处理函数，电平变化触发
  attachInterrupt(M1ENB, readM1EncoderB,
                  CHANGE);  //中断处理函数，电平变化触发
  attachInterrupt(M2ENA, readM2EncoderA,
                  CHANGE);  //中断处理函数，电平变化触发
  attachInterrupt(M2ENB, readM2EncoderB,
                  CHANGE);  //中断处理函数，电平变化触发
  attachInterrupt(M3ENA, readM3EncoderA,
                  CHANGE);  //中断处理函数，电平变化触发
  attachInterrupt(M3ENB, readM3EncoderB,
                  CHANGE);  //中断处理函数，电平变化触发
  attachInterrupt(M4ENA, readM4EncoderA,
                  CHANGE);  //中断处理函数，电平变化触发
  attachInterrupt(M4ENB, readM4EncoderB,
                  CHANGE);  //中断处理函数，电平变化触发

  lastTime = millis();
}

void ReadEncoders(void) {
  int i;
  for (i = 0; i < WHEELS_NUM; i++) {
    if (fixEncoder[i] == 0) {
      Velocity[i] = EncoderCount[i];
    } else {
      Velocity[i] = -EncoderCount[i];
    }
    EncoderCount[i] = 0;
  }
}


/******************时钟***************************/
void Init_timerIsr(void) {
  // 定时中断 
  timer1.attach_ms(interruptTime, timerIsr);  // 打开定时器中断
  interrupts();                               //打开外部中断

/************************* PID *************************/
  //获取电机脉冲数（速度）
  timer_flag = 1;  //定时时间达到标志
  print_Count++;
  for (int i = 0; i < WHEELS_NUM; i++) {
    feedbackPulses[i] = ENC[i].read();

    ENC[i].write(0);  //复位
    outPWM[i] = VeloPID[i].Compute(targetPulses[i], feedbackPulses[i]);
  }
  // motors.setSpeeds(outPWM[0], outPWM[1], outPWM[2], outPWM[3]);
  for(int i = 0; i < WHEELS_NUM; i++){
    Serial.print(outPWM[i]);
    Serial.print(' ');
  }
  Serial.println(' ');
}

//定时器中断处理函数,得到编码器采样周期内的计数并清零
void timerIsr(void) {
  timer_flag = 1;  //定时时间达到标志
  ReadEncoders();
  // RemoteControlRead();
  CheckTimInterupt(MYIRTIME);
}
// 自定义中断
void CheckTimInterupt(int tim) {
  if (millisecond >= tim) {
    millisecond = 0;
    PeriodElapsedCallback(tim);
  } else {
    millisecond++;
  }
}
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

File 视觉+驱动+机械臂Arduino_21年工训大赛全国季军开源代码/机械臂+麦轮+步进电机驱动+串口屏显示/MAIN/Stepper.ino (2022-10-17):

  #include <Arduino.h> 
  #include <AccelStepper.h>  //本示例程序使用AccelStepper库

/*----------------------------------------------*
 *
 *  车身位置及传感器\电机接线:
 *  小车的方位及电电机安装位置，会直接影响麦轮的控制。
 *  Y轴
 *  |           ——> 前
 *  |  左 A - - - - - - - X              左
 *  |  ^  |               |  |     Head
 *  |  |  |               |  V     Head  
 *  |     Z - - - - - - - Y  右          右
 *  |           <—— 后
 *  0-- -- -- -- -- -- -- -- X轴
 *
 * 前后左右行进的麦轮控制：
 *     1-前——>x轴正向: X+ Y+ Z+ A+
 *     2-后——>x轴负向: X- Y- Z- A-
 *     3-左——>y轴正向: X- Y+ Z- A+
 *     4-右——>y轴负向: X+ Y- Z+ A-
 *     5-左偏调整——>【顺时针】: X+ Y- Z- A+ 
 *     6-右偏调整——>【逆时针】: X- Y+ Z+ A-
 * 
 ************************************************/
 
//void moveTo(double dxy,double dw,int dir);    // 主要关注 这个函数就可

//void stopHalSec();
//void intiMotors();
//inline  void  runToSpeed();

/*----------------------------------------------*
 *            步进电机端口宏定义（2*4杜邦线）
 *----------------------------------------------*/
// 奇数为 STEP  偶数为 Dir
  #define En_Pin  40  // 步进电机使能端
  #define X_Step  32  // X 电机步进引脚
  #define X_Dir   33  // X 电机步方向进引脚
  #define Y_Step  34 
  #define Y_Dir   35  
  #define Z_Step  36  
  #define Z_Dir   37  
  #define A_Step  38  
  #define A_Dir   39  

/*--------------------------------------------*
 *            步进电机控制对象定义
 *--------------------------------------------*/
  AccelStepper motora(1,A_Step,A_Dir);    //定义步进电机控制对象a
  AccelStepper motorx(1,X_Step,X_Dir); 
  AccelStepper motory(1,Y_Step,Y_Dir);
  AccelStepper motorz(1,Z_Step,Z_Dir);

/*------------------------------------------*
 *        步进电机参数定义(这个得对应修改)
 *------------------------------------------*/
//  全步进- 1.8° | 半步进- 0.9° | 1/4步进- 0.45° | 1/8步进- 0.225°  —— 配置跳线帽
//  一圈：  200步 | 400步 | 800步 | 1600步 

#define D_Wheel        0.0762        //车轮的直径  单位:m  (三英寸麦轮=7.62cm)

#define AllStep         200       //步进电机全步进一圈步数为200  
//#define MicroStep       4       //步进电机细分数（短接帽设置）
//#define TotalStep       800      //4细分下每圈步数:1600步
#define MicroStep       8         //步进电机细分数（短接帽设置）
#define TotalStep       1600      //8细分下每圈步数:1600步

#define ClockWise       HIGH    //顺时针转动
#define AntiClockWise   LOW     //逆时针转动
#define NotSendPluse    false   //不发送脉冲
#define SendPluse       true    //发送脉冲
#define StartUse        true    //开始启用
#define StopUse         false   //停止启用步进电机

/*---------------------------------------------*
 *              比率变量的设定
 *---------------------------------------------*/
const double C_Wheel=M_PI*D_Wheel;              //车轮的周长 单位：m (M_PI--3.1415...)
const double StepOfMeter=TotalStep/C_Wheel;     // 8细分时 步数/米 

const double CarMaxSpeed=6000;                 // 最大步进速度
// const double Acceleration=50;                  // 设置加速度  --- 没用
const double KMaxFre = 6000;                   // 每秒最大步数   单位：步/秒

// 下边这个不用管，后面与 angle_L 相关的也不用管
// ps: 步进电机的基本程序有一部分是参考别人的，其中这里便是。
//     问过写代码的那位，但是他也忘记这个是啥意思了,不过这并不影响后续的使用。

// 暂未明白该变量  设取 v=wr ，取angle_l = r = 410 mm = 0.410 m   90?
const double angle_L=0.410/90;                 // MAYBE?
// const double angle_L=0.323/90;                 // 将设置的小车线速度转化为整体角速度


/*--------------------------------------------*
 *           步进电机移动方向宏定义
 *--------------------------------------------*/
#define MFord     1         //移动方向 :前、后、左、右
#define MBack     2
#define MLeft     3
#define MRight    4
#define RLeft     5         // 用于寻迹时修正方向
#define RRight    6

#define MZX     7           // 可参考ppt - 对角线方向走   // 右上
#define MAY     8           // 右下
#define MXZ     9           // 左下
#define MYA     10          // 左上


/*-------------------------------------------*
 *           步进电机的初始设定方向-次
 *-------------------------------------------*/

 void defaultDir(){     //  正反转 、 步进与否 、 是否启用  （maybe）
    // 初始化正转(顺时针)、不发生脉冲步进、启用
    motorx.setPinsInverted(ClockWise,NotSendPluse,StartUse);//步进电机初始正转向为顺时针，是否发送步进脉冲步进，是否启用步进电机
    motory.setPinsInverted(ClockWise,NotSendPluse,StartUse);
    motorz.setPinsInverted(ClockWise,NotSendPluse,StartUse);
    motora.setPinsInverted(ClockWise,NotSendPluse,StartUse);
 }


/*-------------------------------------------*
 *           步进电机的最大速度-次
 *-------------------------------------------*/
void defaultMaxSpeed(){
  motorx.setMaxSpeed(CarMaxSpeed);
  motory.setMaxSpeed(CarMaxSpeed);
  motorz.setMaxSpeed(CarMaxSpeed);
  motora.setMaxSpeed(CarMaxSpeed);
}

/*-------------------------------------------*
 *            步进电机的初始化
 *-------------------------------------------*/
 void intiMotors(){                  //四个电机共用一个EN，任取其一控制即可
  motorx.setEnablePin(En_Pin);       //设置步进电机使能端口
  defaultDir();                      //设置步进电机初始方向
  defaultMaxSpeed();                 //设置步进电机最大速度
  motorx.enableOutputs();            //步进端口使能
 }


/*-----------------------------------------*
 *           步进电机运动到设定的速度
 *-----------------------------------------*/
inline  void  runToSpeed(){     // .setSpeed(Val) 之后调用。

    motorx.runSpeed();         // 匀速运动 -- 开始运动
    motory.runSpeed();
    motorz.runSpeed();
    motora.runSpeed();

  }
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

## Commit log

2022-10-17 Add files via upload
    参考21年国赛季军开源代码(就是知乎上写了十多篇文章那位)
    [wuliao(可直接3d打印).STL, 参考元器件清单.xlsx, 基础物料.SLDPRT]
2022-11-16 学校提供的Sunnybot波特库，内含示例程序，包括机械臂的使用、电机控制和OpenMV程序等
2022-11-16 OLED显示TFT库
2022-11-19 Chassis and Remote Control by PS2
2022-11-27 两板WiFi通信(含Mac地址)
2022-12-08 2022.12.08通宵成果
2022-12-09 测试代码（全）
